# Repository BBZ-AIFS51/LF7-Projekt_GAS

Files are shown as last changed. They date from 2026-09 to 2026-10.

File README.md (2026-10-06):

<p align="center">
  Projekt GAS: mini security system with keypad, RFID reader and motion sensor
</p>

<p align="center">
  <a href="https://bbz-aifs51.github.io/LF7-Projekt_GAS/"><b>▶ Open the 3D model in your browser</b></a>
  &nbsp;·&nbsp; <a href="https://github.com/BBZ-AIFS51/LF7-Projekt_GAS/wiki">Project wiki (German)</a>
  &nbsp;·&nbsp; <a href="MDs/anleitung.md">User manual (German)</a>
  &nbsp;·&nbsp; <a href="Schaltplan/SCHALTPLAN.png">Schematic</a>
  &nbsp;·&nbsp; <a href="Code/alarm_system/alarm_system.ino">Firmware</a>
</p>

A small alarm system on an Arduino Uno R3, built as a school project for
learning field 7 (LF07). You arm and disarm it with a PIN on a 4x4 keypad or
with an RFID card. While it is armed, the motion sensor triggers a 30-second
siren. The OLED only shows icons: a heart when the system is disarmed, a skull
when it is armed, and a flashing skull during an alarm. You add cards right on
the device, no PC needed.

<p align="center">
  State machine: disarmed, exit delay, armed, alarm and admin menu
</p>

## Features

- **Two ways to arm and disarm:** PIN + `#` on the keypad, or a stored RFID card. Both do exactly the same thing.
- **Exit delay:** After arming you have 10 s to leave the room. The buzzer beeps once per second in the meantime.
- **Alarm:** It starts on motion (only while ARMED) or after **3 wrong tries** (wrong PIN or unknown card). The siren runs for 30 s or until the correct PIN or a known card is used.
- **Feedback:** A bright double tone means OK, a rough buzz means an error. The PIN only shows up as `*`, and a wrong entry briefly shows a ✖.
- **Admin menu on the device:** `A` + admin PIN + `#` opens it. There you add cards (just hold them to the reader), or browse and delete the stored ones. Cards live in the internal EEPROM and survive a new upload.
- **RFID reset:** `B` restarts the RC522 in case a clone module hangs.

## Quick controls

| Key | Action |
|---|---|
| `0`–`9` | enter the PIN (shown as `*`) |
| `#` | confirm the entry |
| `*` | clear the entry · in the admin menu: back / exit |
| `A` | while DISARMED: enter the admin PIN → admin menu |
| `B` | while DISARMED: re-initialise the RFID reader |
| Hold a card to the reader | same as the correct PIN (if the card is stored) |

The full end-user manual (in German) is in [MDs/anleitung.md](MDs/anleitung.md),
and as a PDF in [Anleitung/](Anleitung/Mini%20Security%20System%20Manual.pdf).

## Hardware

| Part | Uno connection | Note |
|---|---|---|
| Arduino Uno R3 | – | ATmega328P, 2 KB SRAM |
| 4x4 keypad | rows R1–R4 → D9–D6, columns C1–C4 → D5–D2 | the sketch scans the matrix itself |
| 1.3" OLED 128x64 | SDA → A4, SCL → A5 | **SH1106** controller, I²C address `0x3C` |
| RFID-RC522 | SS → A0, RST → A1, MOSI → D11, MISO → D12, SCK → D13 | **VCC to 3.3 V**, 5 V destroys the module |
| Motion sensor (PIR) | OUT → A2 | active HIGH |
| Passive buzzer | signal → D10 | driven directly from the pin, no transistor |
| 9 V battery | barrel jack | power supply |

All other VCC pins go to 5 V, all GND pins to a common ground. This uses up
almost every pin on the Uno; only A3 and D0/D1 (serial) are left free. The full parts list
is in [Teile.xlsx](Teile.xlsx).

<p align="center">
  Wiring of all parts to the Arduino Uno
</p>

The original Cirkit Designer schematic is in
[Schaltplan/](Schaltplan/SCHALTPLAN.png) (PNG and SVG).

## 3D-printed case

<p align="center">
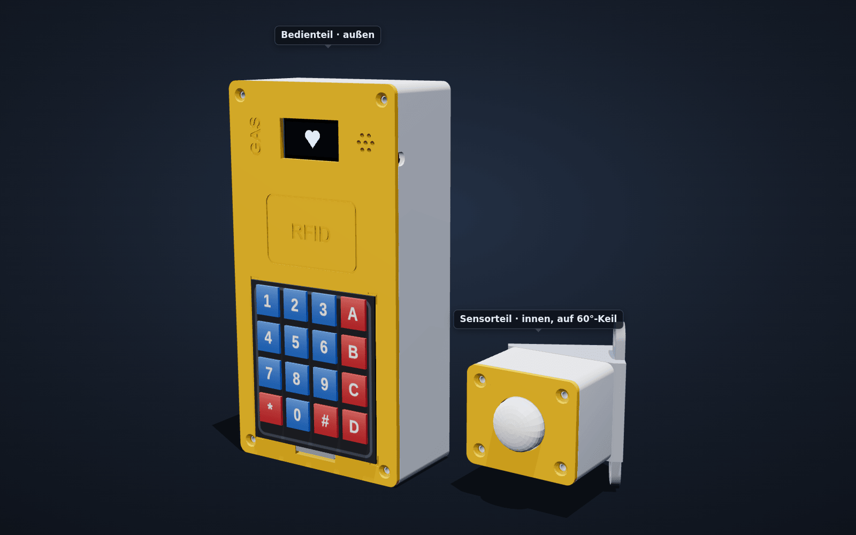
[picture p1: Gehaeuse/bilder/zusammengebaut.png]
Control unit with keypad, OLED and RFID field next to the sensor unit on its wedge
  
</p>

Two printed enclosures, connected by a 3-wire cable: the **control unit** (keypad,
OLED, RC522, buzzer, Uno) goes outside next to the door, the **sensor unit** sits
on the room side on a 60° wedge that turns it towards the entrance. The PIR can't
see through the wall, so standing at the keypad never triggers it. Five STL files,
no supports needed. Planning, print settings and assembly (in German):
[MDs/gehaeuse.md](MDs/gehaeuse.md), model and STLs: [Gehaeuse/](Gehaeuse/).

## Getting started

1. Install the **Arduino IDE** and get these libraries from the Library Manager:
   - **Adafruit SH110X** (also install its dependencies *Adafruit GFX* and *Adafruit BusIO*)
   - **MFRC522** (GithubCommunity)
   - **Keypad** (Mark Stanley / Alexander Brevig), only needed for `hardware_test`
   - `Wire`, `SPI` and `EEPROM` already come with the IDE.
2. Set the PIN and admin PIN at the top of [alarm_system.ino](Code/alarm_system/alarm_system.ino) (`PIN_CODE`, `ADMIN_PIN`).
3. Select the **Arduino Uno** board and the right port, then upload.
4. Set the serial monitor to **9600 baud**. On start-up it shows the RC522 version (`0x91`/`0x92` = OK), the number of stored cards and the free SRAM.
5. On the very first start the EEPROM is empty, so the sketch writes the factory list `DEFAULT_UIDS` into it. After that you manage cards only through the admin menu.

If something doesn't work, the test sketches check each part on its own:

| Sketch | Purpose |
|---|---|
| [Code/alarm_system/](Code/alarm_system/alarm_system.ino) | **Main firmware**: state machine, PIN, RFID, admin menu, sounds |
| [Code/hardware_test/](Code/hardware_test/hardware_test.ino) | bring-up test: OLED, keypad, buzzer, motion sensor |
| [Code/display_test/](Code/display_test/display_test.ino) | OLED only (icons + free SRAM) |
| [Code/rfid_test/](Code/rfid_test/rfid_test.ino) | RC522 only (version, UID of every card) |

## 3D model in the browser

**[▶ bbz-aifs51.github.io/LF7-Projekt_GAS](https://bbz-aifs51.github.io/LF7-Projekt_GAS/)**

An interactive 3D model of the build (three.js), laid out after the schematic.
It runs the firmware logic from `alarm_system.ino`, so the states, timings,
sounds and OLED graphics are the same:

- Press keys on the 3D keypad or in the side panel. Your keyboard works too (Enter = `#`, Esc = `*`).
- Click the cards or the key fob: they float over to the RC522 and the SPI lines light up.
- Click the motion sensor to trigger the alarm while ARMED.
- A signal pulse travels along each wire. A key press lights up exactly its row and column wire, and the L LED on D13 flickers during SPI traffic.
- The buzzer plays through WebAudio, and there is a serial monitor and an EEPROM card list.
- The **Enclosure** tab ([direct link](https://bbz-aifs51.github.io/LF7-Projekt_GAS/#enclosure)) puts the same parts into the 3D-printed case, built from the real STL files. Show the case solid, as X-ray or hidden, open it, and watch the signals run through the wires and the cable to the sensor unit.

The model uses demo PINs (`1234` and admin `0000`), not the real ones from the
sketch. To use it offline, just open
[docs/viewer/index.html](docs/viewer/index.html) in your browser.

## Pitfalls we solved

- **The OLED is an SH1106, not an SSD1306.** With the SSD1306 library it stays blank or only shows stripes. The right class is `Adafruit_SH1106G`.
- **SRAM is tight.** The OLED buffer alone takes 1024 of the 2048 bytes. With the Keypad library only ~205 bytes were left, which caused resets and wrong key presses. So the sketch scans the matrix itself, and all strings are kept in flash with `F()`.
- **`SPI.begin()` drives D10 HIGH**, because D10 is the AVR's SS pin. That is exactly where the buzzer sits, so the sketch sets the buzzer pin LOW only *after* `SPI.begin()`.
- **The motion sensor moved to A2**, because D11 is the fixed SPI MOSI pin. A2 works just like any digital pin with `digitalRead()`.
- **Polling the RC522 blocks for ~25 ms** when no card is present. So the sketch only polls the reader every 200 ms, otherwise the keypad gets sluggish and the siren stutters.

## Project structure

| Folder/file | Contents |
|---|---|
| [Code/](Code/) | Arduino sketches, one subfolder per sketch |
| [docs/](docs/) | animated README graphics (SVG), the 3D viewer (`docs/viewer/`) and the social preview image |
| [Gehaeuse/](Gehaeuse/) | 3D-printable case: OpenSCAD model, STL files, pictures |
| [tools/](tools/) | scripts that put the STLs into the viewer and render the pictures |
| [wiki/](wiki/) | source of the project wiki (German), published automatically by `.github/workflows/wiki.yml` |
| [MDs/](MDs/) | docs (German): [hardware spec](MDs/aufbau.md), [user manual](MDs/anleitung.md), [development log](MDs/entwicklungsverlauf.md) |
| [Anleitung/](Anleitung/) | user manual as a PDF |
| [Schaltplan/](Schaltplan/) | schematic (PNG/SVG) |
| [Teile.xlsx](Teile.xlsx) | parts list |
| [CLAUDE.md](CLAUDE.md) | project context and hardware facts for development with Claude Code |

The firmware was written together with Claude Code. Every prompt and answer is
logged (in German) in [MDs/entwicklungsverlauf.md](MDs/entwicklungsverlauf.md).
The school project documentation (assignment, team, schedule, costs, a visual
timeline of the development log, reflection) lives in the
[project wiki](https://github.com/BBZ-AIFS51/LF7-Projekt_GAS/wiki) (German). Its pages
are edited in [wiki/](wiki/); every push to `main` publishes them to the wiki.

## License

[MIT](LICENSE). The 3D viewer uses [three.js](https://threejs.org/) (MIT,
bundled as `docs/viewer/three.min.js`).

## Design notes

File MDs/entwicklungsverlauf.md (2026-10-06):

# Entwicklungsverlauf — Projekt GAS

Dokumentation der Firmware-Entwicklung mit Claude Code (Claude Opus 5).
Chronologisches Protokoll: Prompts (Jan Mummert) und Antworten (Claude).

- Projekt: LF07 — Mini-Sicherheitssystem / Access Lock (Arduino Uno R3)
- Daten der Sitzungen: 08.09.2026, 22.09.2026, 23.09.2026 (inkl. Gehäuse),
  29.09.2026, 30.09.2026, 06.10.2026
- Grundlagen im Kontext: [../CLAUDE.md](../CLAUDE.md), [aufbau.md](aufbau.md)

---

## 1. Prompt — Auftrag: komplette Firmware

> Use @CLAUDE.md und @MDs/aufbau.md.
>
> Programmiere den kompletten Code für unser Projekt.
>
> Was wir wollen: Ein mini Sicherheitssystem/Doorlock/Access Lock.
> Der Buzzer soll einen Alarmton abspielen, wenn der Motion sensor ausgelöst
> ist. Man soll die Alarmanlage mit einem Pin (später auch mit rfid, aber das
> ist nur eine Idee für ein feature wenn alles läuft) entschärfen können und
> auch wieder mit dem Pin scharf schalten können. Das Display soll im scharfen
> zustand einen Totenkopf anzeigen, wenn man Pin eingibt sollen anstelle des
> Pins nur Sternchen "*" angezeigt werden, die Eingabe des Pins soll man mit
> "#" bestätigen können. Bei richtigem Pin soll ein heller angenehmer
> Bestätigungston kommen, Bei Falsch eingabe ein Rauer längerer Ton (3sek).
> Bei 3 facher fehleingabe soll der Alarm der Anlage ertönen.
> Im Entsperrten zustand soll das Display ein Herz anzeigen.
>
> Im Unscharfen zustand soll der Motion Sensor natürlich keinen Alarm auslösen,
> nur wenn die Anlage scharf ist.
> Der Alarm soll extrem laut und schrill sein, er soll 30 sekunden dauern.

### Antwort

Fertig: [../Code/alarm_system/alarm_system.ino](../Code/alarm_system/alarm_system.ino)
— die komplette Firmware, Pins genau wie in aufbau.md/CLAUDE.md
(SDA=A4, SCL=A5, SH1106 @0x3C).

**Zustände**

- `UNSCHARF` — Herz auf dem Display, Bewegungssensor wird ignoriert.
- `SCHARF IN xs` — Ausgangsverzögerung (10 s, Piep pro Sekunde), damit du nach
  dem Scharfschalten den Raum verlassen kannst, ohne dich selbst auszulösen.
  Das hattest du nicht verlangt, ohne das löst die Anlage aber sofort beim
  eigenen Zurücktreten aus — Wert steht als `EXIT_DELAY_MS` oben, auf 0 setzen
  wenn du es nicht willst.
- `SCHARF` — Totenkopf, Bewegung (steigende Flanke auf D11) löst Alarm aus.
- `ALARM` — blinkendes „ALARM!!", Totenkopf, Restsekunden; Sirene 30 s, danach
  automatisch wieder scharf.

**Bedienung am Keypad**

- `0-9` PIN eingeben, auf dem Display nur `*` (Größe 2, mittig)
- `#` bestätigen → richtiger PIN schaltet scharf/unscharf und beendet den
  laufenden Alarm sofort
- `*` Eingabe löschen; halb getippte PIN verfällt nach 10 s von selbst
- PIN steht oben als `const char PIN_CODE[] = "1234";`

**Töne** (nicht-blockierend, Keypad bleibt währenddessen bedienbar)

- Richtig: zwei helle kurze Noten (G6 → C7)
- Falsch: rauer tiefer Brummton, 3 s (schnelles Wechseln 95/135 Hz)
- 3× falsch: voller Alarm — das gilt in jedem Zustand, also auch im unscharfen
  (Sabotage). Wenn du das nur im scharfen Zustand willst, sag Bescheid.
- Alarm: Sirenen-Sweep 2500↔3700 Hz, bewusst im lautesten Bereich des Piezos,
  30 s

**Nicht verifiziert:** Ich konnte den Sketch hier nicht kompilieren —
arduino-cli ist auf dem Rechner nicht vorhanden. Bitte einmal in der Arduino
IDE bauen und hochladen; die Bibliotheken sind dieselben wie beim
`hardware_test`.

---

## 2. Prompt — Display zeigt Pixelmüll

> Das Display bugt ein wenig, es zeigt weder das herz, noch einen totenkopf
> oder ähnliches an. Auch der Code etc. wird nicht richtig angezeigt. man kann
> die sekundne timer erahnen, aber das wars. Das display hat diese specs:
>
> - Module dimensions: 36 mm x 34 mm x 3 mm
> - Dot Matrix: 128 x 64
> - Pixel size: 0.21 mm × 0.21 mm
> - Pixel pitch: 0.23 mm × 0.23 mm
> - Display Mode: Passive Matrix
> - Duty: 1/64 Duty
> - Display Color: Blue
> - Interface: I2C
> - Power consumption: Less then 11mA
> - Size: 1.3 inch

### Antwort

Das klingt nach einem Anzeige-/Speicherproblem, nicht nach falscher Geometrie —
1,3" 128x64 I2C ist praktisch immer der SH1106, und der `hardware_test` lief ja.
Ich mache zwei Dinge: einen isolierten Display-Test zum Eingrenzen und die
Hauptfirmware deutlich RAM-sparsamer.

Der wahrscheinlichste Verdacht: Der Uno hat 2 KB SRAM, der Framebuffer belegt
davon allein 1 KB. `snprintf("%lu")` und die Text-Literale im RAM treiben den
Stack so weit hoch, dass er in den Framebuffer läuft — das ergibt genau so ein
Bild, in dem man Reste (die Sekundenzahlen) noch erahnen kann.

Zwei Sachen, bitte in dieser Reihenfolge testen:

**1. [../Code/display_test/display_test.ino](../Code/display_test/display_test.ino)
hochladen** (nur das Display, sonst nichts). Er zeigt im 2-Sekunden-Takt:
Rahmen+Text → Herz → Totenkopf → `****`, und schreibt vor jedem Bild den freien
SRAM in den Seriellen Monitor.

- Sehen die vier Bilder korrekt aus → das Display kann alles, das Problem ist
  der Speicher im Hauptsketch (siehe Punkt 2).
- Sind sie auch hier kaputt → es liegt am Display selbst; dann sag mir bitte,
  *wie* kaputt (verschoben, gestreift, Rauschen) und was der Rahmen macht. Dann
  ist der Controller vermutlich doch kein SH1106, und ich baue auf SSD1306 bzw.
  auf einen Spaltenversatz um.

**2. [../Code/alarm_system/alarm_system.ino](../Code/alarm_system/alarm_system.ino)
ist überarbeitet.** Was ich geändert habe und warum:

Der Uno hat 2048 Byte SRAM, davon frisst der OLED-Framebuffer allein 1024. Dazu
Keypad-Library, Wire- und Serial-Puffer — es bleiben nur ein paar hundert Byte
Stack. `snprintf("%lu")` braucht davon über 100 Byte auf einen Schlag, und die
Text-Literale `"UNSCHARF"` usw. lagen zusätzlich im RAM. Wenn der Stack in den
Framebuffer läuft, sieht man genau das, was du beschreibst: Pixelmüll, in dem
man Reste (deine Sekundenzahlen) noch erahnen kann.

Deshalb jetzt:

- kein `snprintf` mehr — der Countdown wird direkt mit `display.print()`
  ausgegeben
- alle Display-Texte über `F(...)` im Flash statt im RAM
- keine temporären `char`-Puffer mehr (die Sternchen werden in einer Schleife
  gedruckt)
- `setup()` gibt `free SRAM:` über Serial aus — der Wert sollte deutlich über
  250 liegen

Der Funktionsumfang ist unverändert. Die Icons habe ich zusätzlich leicht
anders positioniert, damit sich Totenkopf und die Sternchen-Zeile nicht mehr
überlappen.

Melde mir die vier Testbilder und den SRAM-Wert, dann weiß ich, in welche
Richtung es geht. Kompilieren kann ich hier weiterhin nicht — auf dem Rechner
ist keine arduino-cli installiert.

---

## 3. Prompt — Dokumentation

> Packe alle Prompts von mir und deine antworten in einer .md datei. wir
> brauchen das als dokumentation

### Antwort

Dieses Dokument. Es wird bei weiteren Änderungen fortgeschrieben.

---

## 4. Prompt — Resets beim Scharfschalten, Text soll weg

> Funktioniert soweit.
>
> 1. Sehr oft, nachdem es einmal armed und disarmed wurde kann man es nicht
>    erneut armen. Es zeigt im serial pin wrong an obwohl dieser richtig
>    eingegeben wurde:
>
>    ```
>    free SRAM: 205
>    [PIN] wrong 1
>    [PIN] correct
>    [STATE] arming - exit de=== Alarm system ready (disarmed) ===
>    PIN + '#' arms / disarms, '*' clears the entry.
>    free SRAM: 205
>    [PIN] wrong 1
>    ```
>
> 2. Entferne den Text bei den Symbolen, es soll nur Totenkopf oder Herz ohne
>    Text angezeigt werden. Der Sekundentimer ist etwas zu groß, die hälfte der
>    Zahl verschwindet weil es über den display rand hinaus geht.

### Antwort

**Zu 1 — der Arduino startet neu.** Im Log bricht die Zeile
`[STATE] arming - exit de` mitten im Wort ab und danach kommt wieder der
Startbanner `=== Alarm system ready ===`. Das ist ein Reset, kein Logikfehler.
Ursache ist der freie SRAM: **205 Byte**. Davon muss der komplette Stack leben,
inklusive der Interrupts, die `tone()` erzeugt (bei 3700 Hz sind das 7400
Interrupts pro Sekunde). Wenn so ein Interrupt zuschlägt, während der
Display-Code tief im Stack steht, läuft der Stack in den Framebuffer und in die
globalen Variablen — mal gibt es einen Reset, mal wird nur `entry[]` verfälscht,
und dann meldet der Sketch „PIN wrong" obwohl richtig getippt wurde. Das erklärt
auch, warum es erst *nach* dem ersten Scharfschalten auftritt: vorher hat noch
kein Ton gespielt.

Der größte Speicherfresser nach dem Framebuffer war die **Keypad-Library**: sie
hält 10 `Key`-Objekte, eine Bitmap und die Keymap im RAM, zusammen rund 120 Byte.
Die habe ich rausgeworfen und den 4x4-Scan selbst geschrieben — für eine Matrix
sind das ungefähr 30 Zeilen:

- Zeilen auf `INPUT_PULLUP`, Spalten hochohmig (`INPUT`)
- pro Scan eine Spalte auf `OUTPUT`/LOW ziehen und die vier Zeilen lesen
- Keymap liegt jetzt im Flash (`PROGMEM` + `pgm_read_byte`)
- eigenes Entprellen (20 ms), eine Taste wird genau einmal beim Drücken gemeldet

Damit sollten rund **320–330 Byte** frei sein. Der Wert steht wie vorher beim
Start im Seriellen Monitor — bitte einmal nachsehen und mir sagen, was dasteht.
Zusätzlich gibt der Sketch jetzt jede erkannte Taste (`[KEY] 4`) und die
komplette Eingabe vor der Prüfung (`[PIN] entered: 1234`) aus. Falls doch noch
etwas verschluckt wird, sieht man es damit sofort.

Die Keypad-Library wird für diesen Sketch nicht mehr gebraucht; der
`hardware_test` benutzt sie weiterhin, also bitte installiert lassen.

**Zu 2 — Anzeige.** Aller Statustext ist raus, es gibt nur noch die Icons:

- UNSCHARF: Herz, mittig
- SCHARF: Totenkopf, mittig
- Ausgangsverzögerung: Totenkopf + Countdown darunter
- ALARM: Totenkopf, der im 250-ms-Takt das ganze Display invertiert, darunter
  die Restsekunden (auch das „ALARM!!" ist weg — sagt Bescheid, wenn ihr das
  Wort zurückhaben wollt)

Der abgeschnittene Countdown war ein vertikales Problem, kein horizontales: die
Zahl stand in Größe 2 auf y = 52, das sind 16 Pixel Höhe bis y = 68 — das
Display hört bei 63 auf, also fehlte die untere Hälfte. Jetzt sitzt sie auf
y = 46 bzw. y = 47 und passt.

Während der PIN-Eingabe zeigt das Display nur noch die Sternchen, groß und
mittig. Grund: Totenkopf und Sternchen brauchen zusammen mehr als 64 Pixel Höhe,
sie hätten sich sonst überlappt.

---

## 5. Prompt — Kollisionserkennung und Rechtevergabe bei RFID

> Erkläre uns was unsere Lehrerin mit Kollisionserkennung und Rechtevergabe im
> bezug auf RFID meint

### Antwort

Zwei verschiedene Ebenen, die beim RFID-Teil oft durcheinander geworfen werden:

**Kollisionserkennung — Protokoll-Ebene (ISO 14443A)**

Liegen mehrere Karten gleichzeitig im Feld des RC522, würden bei einer
einfachen Anfrage alle gleichzeitig antworten — das ist eine *Kollision*. Der
ISO-14443A-Standard löst das über ein Anti-Kollisions-Verfahren: Der Reader
fragt die UID Bit für Bit in Kaskaden ab, bis genau eine Karte eindeutig
identifiziert ist. Bei uns läuft das komplett innerhalb der MFRC522-Library ab,
über die Aufrufe

```cpp
mfrc522.PICC_IsNewCardPresent()
mfrc522.PICC_ReadCardSerial()
```

in [readRfidUid()](../Code/alarm_system/alarm_system.ino#L326). Der Aufruf
[mfrc522.PICC_HaltA()](../Code/alarm_system/alarm_system.ino#L339) danach
schickt die gelesene Karte in den HALT-Zustand, damit sie nicht bei jedem
Poll-Zyklus erneut "kollidiert" bzw. neu gelesen wird, solange sie liegen
bleibt.

**Rechtevergabe — Anwendungsebene (Access Control)**

Unsere jetzige Logik ist rein binär: Eine UID steht in
[ALLOWED_UIDS](../Code/alarm_system/alarm_system.ino#L77) oder nicht, geprüft
in [isAllowedUid()](../Code/alarm_system/alarm_system.ino#L350) — jede erlaubte
Karte darf alles, was das System kann (scharf/unscharf schalten). Mit
"Rechtevergabe" ist vermutlich eine feinere Unterscheidung gemeint, z. B.:

- unterschiedliche Rollen pro Karte (manche dürfen nur entschärfen, andere
  auch neue Karten anlernen)
- Karten zur Laufzeit hinzufügen/entziehen können, statt sie fest im Code
  (`PROGMEM`) zu hinterlegen
- Protokollierung, wer wann welche Karte benutzt hat, statt nur ja/nein

Für den Umfang dieses Schulprojekts bleibt es bei der einfachen
Allow-List-Prüfung — das oben ist als konzeptionelle Erklärung für die
Dokumentation/Präsentation gedacht, nicht als Implementierungsauftrag.

---

## 6. Prompt — Rechtevergabe umsetzen: UIDs außerhalb des Codes verwalten

> Thema Rechtevergabe. Man soll die uids außerhalb des Codes verändern, bzw.
> sperren oder hinzufügen können. Wie könnte man das lösen. Plane erst

### Antwort

Aufbauend auf Eintrag 5 (dort nur konzeptionell besprochen, bewusst nicht
umgesetzt) jetzt tatsächlich implementiert, nach Rückfrage zur Bedienung:

- Admin-Interface komplett über Keypad + OLED (keine Serial-Kommandos, kein
  PC nötig)
- Löschen entfernt eine UID sofort, keine separate Sperrliste

**Speicherung:** UIDs liegen jetzt im internen EEPROM des Uno statt fest im
Code (`DEFAULT_UIDS` bleibt nur als Werksvorgabe fürs allererste Booten).
Kein Zusatzmodul (z. B. SD-Karte) nötig und laut CLAUDE.md auch gar nicht
möglich — kein Pin mehr frei. EEPROM übersteht ein Neu-Hochladen des Sketches.

**Bedienung:** Taste `A` im UNSCHARF-Zustand + eine eigene `ADMIN_PIN` + `#`
öffnet einen neuen Zustand `STATE_ADMIN` mit kleinem Text-Menü auf dem OLED
(bisher zeigte das Display nur Icons — hier bewusste Ausnahme, siehe
[Code/alarm_system/alarm_system.ino](../Code/alarm_system/alarm_system.ino#L885)):

- `1` Karte anlernen — auflegen genügt, kein manuelles Abtippen der Hex-UID
  mehr (das war vorher nötig, siehe `rfid_test.ino`)
- `2` Liste durchblättern (`#`), Karte löschen (`D`)
- `*` Menü verlassen; nach `ADMIN_IDLE_TIMEOUT_MS` (20 s) auch automatisch

Eine falsche Admin-PIN läuft über denselben `accessDenied()`-Pfad wie eine
falsche normale PIN — zählt also zu den 3 Fehlversuchen und löst genauso
Alarm aus (Bruteforce-Schutz für beide PINs einheitlich).

`MAX_STORED_UIDS` bewusst klein (8) gewählt wegen des knappen SRAMs (siehe
Memory Note in CLAUDE.md) — mehr Platz wäre im EEPROM (1024 Byte) locker da,
das RAM ist der eigentliche Engpass.

Vor der Änderung wurde eine Kopie der alten Version unter
`Code/alarm_system/alarm_system.ino.bak` gesichert.

**Offener Punkt:** Wie in Eintrag 4 — kein `arduino-cli` auf diesem Rechner,
der Sketch wurde nicht kompiliert. Vor dem Hochladen in der Arduino IDE
verifizieren und danach die Punkte aus dem Plan durchgehen (u. a.: passt
`free SRAM` noch, wandert die bestehende `DEFAULT_UIDS`-Karte korrekt ins
EEPROM, funktioniert Anlernen/Löschen, löst 3x falsche Admin-PIN den Alarm
aus, übersteht eine neue Karte ein erneutes Hochladen).

---

## 7. Prompt — RFID-Reset (22.09.2026)

> Unsere Lehrerin hat bei einer anderen Gruppe angemerkt, dass sie keinen
> RFID-Reset haben, da sich das RFID-Modul wohl öfters mal aufhängen kann.
> Wie könnten wir sowas bei uns einbauen, bzw. ist das überhaupt nötig? Falls
> ja könnte man da ja auch z. B. den Buchstaben B beim Tastenfeld setzen.

### Antwort

Ja, sinnvoll: RC522-Klone können SPI-seitig hängen bleiben (`VersionReg`
antwortet dann wieder mit `0x00`/`0xFF` statt `0x91`/`0x92`), erkennbar an
Karten, die plötzlich nicht mehr gelesen werden — sonst hilft nur ein
kompletter Neustart des Uno. `RST_PIN` (A1) ist bei uns ohnehin schon
verdrahtet, ein Reset zur Laufzeit ist also reine Software.

Rückfrage, ob nur manuell per Taste, zusätzlich automatisch im Hintergrund,
oder gar nicht — Antwort: nur manuell. Umgesetzt in
[../Code/alarm_system/alarm_system.ino](../Code/alarm_system/alarm_system.ino):

- Neue Funktion `resetRfid()` (`PCD_Reset()` + `PCD_Init()`, danach
  `VersionReg` neu geprüft und `rfidOk` aktualisiert; OK-/Fehlerton als
  Feedback)
- Taste `B` im Zustand UNSCHARF ruft `resetRfid()` auf — bisher unbelegt,
  analog zur `A`-Abfrage fürs Admin-Menü (nur bei `entryLen == 0`)
- Kopf-Kommentar im Sketch und [../CLAUDE.md](../CLAUDE.md) (Abschnitt
  „Sketches") entsprechend ergänzt

**Offener Punkt:** wie in den vorherigen Einträgen nicht kompiliert (kein
`arduino-cli` auf dem Rechner) — vor dem nächsten Hochladen in der Arduino
IDE prüfen, außerdem am echten Aufbau testen, ob `B` den Reader nach einem
gezielten Verbindungsabbruch (z. B. RST kurz trennen) tatsächlich wiederbelebt.

---

## 8. Prompt — 3D-Animationen und neue README (23.09.2026)

> Schaue dir dieses Github Repo von einem freund an:
> https://github.com/BBZ-AIFS51/LF7-MiniCasino
>
> Ich möchte das in dem Github repo von diesem Projekt auch so coole 3d
> animationen wie bei denen sind. Verwende dafür unsere dokumentation. Dabei
> kannst du Auch gleich die README unseres Projekts einmal komplett überarbeiten

### Antwort

Das MiniCasino-Repo nutzt zwei Dinge: animierte SVG-Grafiken direkt in der
README (CSS-Animationen, laufen auch auf GitHub) und einen three.js-3D-Viewer,
der über GitHub Pages läuft. Beides gibt es jetzt auch bei uns, aufgebaut aus
CLAUDE.md, aufbau.md, anleitung.md, dem Schaltplan und der Firmware:

- [../docs/banner.svg](../docs/banner.svg): isometrisches Gerät, das in 10 s
  einmal UNSCHARF → PIN → SCHARF → ALARM durchläuft. Herz und Totenkopf mit
  denselben Koordinaten wie `drawHeart()`/`drawSkull()`, die Alarm-Anzeige
  invertiert wie im Sketch, dazu eine schwebende RFID-Karte.
- [../docs/how-it-works.svg](../docs/how-it-works.svg): Zustandsautomat mit
  laufenden Pfeilen, dem jeweils aktiven Zustand und Fortschrittsbalken für
  10 s / 30 s.
- [../docs/wiring.svg](../docs/wiring.svg): Verdrahtung am Uno, Signalpulse
  zeigen die Richtung, Hinweis auf 3,3 V beim RC522.
- [../docs/viewer/index.html](../docs/viewer/index.html): 3D-Modell des
  Steckbrett-Aufbaus nach dem Schaltplan. Die Firmware-Logik ist 1:1 nach
  JavaScript übertragen (Zustände, Zeiten, Töne über WebAudio, OLED als
  128x64-Framebuffer mit denselben GFX-Aufrufen, Admin-Menü, EEPROM im
  localStorage). Tasten, Karten und PIR sind anklickbar, Signalpulse laufen
  über die Kabel. Im Modell gelten Demo-PINs (`1234`/`0000`), nicht die echten.
- [../.github/workflows/pages.yml](../.github/workflows/pages.yml): veröffentlicht
  den Viewer auf GitHub Pages.
- [../README.md](../README.md) komplett neu geschrieben.

Getestet: SVGs und Viewer im Edge (headless) gerendert, die Viewer-Logik mit
einem Skript durchgespielt (PIN, Ausgangszeit, Bewegung → Alarm,
3 Fehlversuche, Admin-PIN, Karte anlernen/löschen, 7-Byte-UID abgelehnt,
Eingabe-Timeout). Alle Prüfungen sind bestanden.

**Offener Punkt:** GitHub Pages muss einmalig unter *Settings → Pages →
Source: GitHub Actions* aktiviert werden. Der Fehlerton dauert laut Sketch
`ERROR_TONE_MS = 2000` (2 s), Kommentare und CLAUDE.md sagen noch 3 s.

---

## 9. Prompt — README, Grafiken und Viewer auf Englisch (23.09.2026)

> Ändere die Readme auf englisch
>
> Ja stelle auch den viewer auf englisch um und pushe alles dann

### Antwort

[../README.md](../README.md) ins Englische übersetzt (Inhalt unverändert,
deutsche Doku-Links mit „(German)“ markiert). Alle Texte in den drei SVGs unter
[../docs/](../docs/) und die komplette Oberfläche des 3D-Viewers (Seitenleiste,
Tooltips, Beschriftungen, Kartenaufdrucke) sind jetzt englisch. Die OLED- und
Serial-Texte waren schon englisch, weil sie aus dem Sketch stammen. Grafik und
Viewer danach erneut gerendert und geprüft.

---

## 10. Prompt — Gehäuse für den 3D-Druck (23.09.2026)

> Plane und entwerfe ein Gehäuse. Das Gehäuse soll 3D gedruckt werden. Ich habe
> 0 Erfahrung was sowas angeht.
>
> Wichtig ist, dass der Bewegungssensor auf der anderen seite sein muss, also
> quasi ist alles vorne an einer tür/Türrahmen und auch der anderen seite ist
> der bewegungssensor, sodass er halt erst was erkennt wenn man den raum
> betritt und nicht auslöst wenn man nur an den türrahmen rantritt um es zu
> entsperren.
>
> Plane erst das Gehäuse, dann entwerfe es

### Antwort

Zwei Gehäuse statt einem: **Bedienteil** außen neben der Tür (Uno, Keypad,
OLED, RC522, Buzzer, 90 × 176 × 45 mm) und **Sensorteil** innen im Raum
(HC-SR501, 52 × 44 × 35 mm), verbunden über ein 3-adriges Kabel. Der PIR sieht
nur in direkter Sichtlinie, die Wand verdeckt also die Person am Bedienteil.

- [gehaeuse.md](gehaeuse.md): Planung (Konzept, Aufteilung, Montageort) und
  Einsteiger-Anleitung (Nachmessen, Slicen, Einkaufsliste, Zusammenbau,
  Anpassen in OpenSCAD).
- [../Gehaeuse/gehaeuse.scad](../Gehaeuse/gehaeuse.scad): parametrisches
  OpenSCAD-Modell, alle Maße oben als Variablen.
- [../Gehaeuse/stl/](../Gehaeuse/stl/): vier fertige Druckteile, bereits in
  Druckrichtung, ohne Stützstrukturen druckbar.

Mit OpenSCAD 2021.01 gerendert: alle vier STLs sind geschlossen („Simple:
yes“). Die Frontansicht wurde auf nicht gespiegelte Gravuren geprüft.
**Offener Punkt:** Die Modulmaße stammen aus Datenblättern und sind nicht am
echten Aufbau gemessen. Außerdem ist noch nichts gedruckt.

---

## 11. Prompt — Sensor schräg zur Tür (29.09.2026)

> Passe montage.svg so an, dass der Sensor den Eingang abschirmt (grob im
> Bild angezeichnet). Passe außerdem sensor.png und die 3D-Dateien so an,
> dass der Sensor ein wenig angewinkelt an der Wand sitzt, sodass er den
> kompletten Eingang abschirmt.

### Antwort

Neues Druckteil **Keil** (`sensor_wedge`, 30°, 5–31 mm dick): wird mit zwei
Laschen an die Wand geschraubt, das unveränderte Sensor-Rückteil sitzt mit
2 Schrauben 3 × 10 mm darauf. Das dünne Ende zeigt zur Tür; bei 110°
Öffnungswinkel liegt die türseitige Kante des Erfassungsbereichs dann fast
parallel zur Wand, der ganze Eingang ist im Sichtfeld. Für die andere Türseite
wird der Keil um 180° gedreht.

- `montage.svg`: Erfassungsbereich um 30° zur Tür gedreht, Keil eingezeichnet.
  Außerdem das Türscharnier auf die andere Seite gelegt — sonst stünde die
  geöffnete Tür genau zwischen Sensor und Eingang.
- `sensor.png`, `explosion.png`, `zusammengebaut.png` neu gerendert,
  `stl/sensor_wedge.stl` neu (geschlossen, „Simple: yes“). Die übrigen STLs
  sind unverändert.
- [gehaeuse.md](gehaeuse.md): Keil, Montage, Einkaufsliste ergänzt.

---

## 12. Prompt — Sensor noch stärker zur Tür (29.09.2026)

> Noch mehr die Tür abdecken, sodass sich der Sensorbereich stark mit der
> Wand überschneidet.

### Antwort

Keil von 30° auf **60°** (`su_angle`), jetzt 5–50 mm dick. Die türseitige
Kante des Erfassungsbereichs läuft damit ca. 25° in die Wand hinein, die
andere zeigt fast gerade in den Raum. Damit die Schraubenlöcher am dicken
Ende nicht hinten aus dem Keil kommen, hat er dort 4 mm zusätzliches Material
(`wedge_back`). `montage.svg` (Kegel an der Wandaußenseite abgeschnitten, weil
der PIR nicht durch die Wand sieht), `sensor.png`, `explosion.png`,
`zusammengebaut.png` und `stl/sensor_wedge.stl` („Simple: yes“) neu erzeugt.

---

## 13. Prompt — Vorschaubilder, Gehäuse im 3D-Viewer, Social Preview (30.09.2026)

> 1. Überarbeite Optisch nochmal die Vorschauen für das 3D-Druck Modell.
> 2. Ergänze beim 3D-Modell im Browser noch einen Tab, in welchem das ganze
>    nicht nur lose da liegt, sondern auch im Gehäuse ist. Das Gehäuse soll bei
>    diesem Modell dann quasi durchsichtig oder umschaltbar sein
> 3. Erstelle ein Passendes Social Media Preview nach den vorgaben von gitbhub

### Antwort

**Gehäuse im 3D-Viewer:** neuer Tab **Enclosure** (Direktlink
`…/LF7-Projekt_GAS/#enclosure`). Bedienteil vorne auf einem Demo-Brett (spielt
die Wand), Sensorteil auf dem 60°-Keil auf der Rückseite, 3-adriges Kabel durch
das Brett. Innen sitzen Uno, Keypad, OLED, RC522, Buzzer und ein Mini-Breadboard
an den Positionen aus `gehaeuse.scad`, alle Kabel sind verlegt. Das Gehäuse lässt
sich **Solid / X-ray / Hidden** schalten und mit **Open** aufklappen. Die
Firmware läuft weiter: Tasten, Karten (fliegen ans RFID-Feld), Bewegungsmelder
(Signal läuft sichtbar übers Kabel, der Erfassungsbereich leuchtet auf).
Die Gehäuseteile sind keine Nachbauten, sondern die echten STL-Dateien:
`tools/stl2viewer.mjs` packt sie kompakt in `docs/viewer/enclosure.js` (233 KB,
funktioniert auch offline). Nebenbei die Befestigungslöcher des Uno im Viewer
auf die echten R3-Maße korrigiert, damit er auf den Abstandshaltern sitzt.

**Vorschaubilder:** alle sechs Bilder in `Gehaeuse/bilder/` neu, jetzt im Stil
der README-Grafiken (dunkler Hintergrund, weiche Schatten, Studio-Licht,
Beschriftungen auf Deutsch) und mit den detaillierten Bauteilen aus dem Viewer
statt der groben OpenSCAD-Platzhalter. Neu dazu `druckplatte.png`: alle fünf
Teile so, wie sie auf dem Druckbett liegen (in `gehaeuse.md` bei „Slicen“).
Erzeugt werden die Bilder von `tools/render.mjs` über den Viewer (Playwright),
optional mit pngquant verkleinert (je 35–115 KB).

**Social Preview:** `docs/social-preview.png`, 1280 × 640 px (GitHub-Empfehlung,
Minimum 640 × 320), PNG unter 1 MB (135 KB), wichtige Inhalte mit Abstand zum
Rand. Titel, Kurzbeschreibung und die vier Funktionen wie im Banner, rechts das
Gehäuse im X-ray-Modus. Vorlage: `tools/social-preview.html`. **Muss von Hand
hochgeladen werden:** Repository → Settings → General → Social preview → Edit →
Upload an image (dafür gibt es keine API).

---

## 14. Prompt — Banner und Social Preview mit Gehäuse (30.09.2026)

> dann aktualisiere auch docs/banner.svg, sodass auch dort sowie auf dem social
> preview banner das ganze im gehäuse drauf ist

### Antwort

- `docs/banner.svg`: Statt der flachen Platine zeigt das Banner jetzt das
  Bedienteil im Gehäuse (isometrisch, stehend) und daneben das Sensorteil auf
  dem 60°-Keil. Alle Positionen stammen aus `gehaeuse.scad`: OLED-Fenster,
  Schalllöcher, „GAS“- und „RFID“-Gravur, Keypad, Kabelschlitz, Schrauben.
  Die Animation läuft wie vorher: Herz, PIN-Eingabe mit Tastendrücken,
  Totenkopf, Alarm mit Blinken, rotem Schein und Ringen an Buzzer und
  Bewegungsmelder. Die Karte schwebt vor dem RFID-Feld. Weiterhin reines SVG
  mit CSS-Animation (19 KB), keine eingebetteten Bilder.
- `docs/social-preview.png`: Gehäuse jetzt massiv statt X-ray, damit klar das
  fertige Gerät zu sehen ist (1280 × 640, 110 KB). Muss danach wieder unter
  Settings → General → Social preview hochgeladen werden.

---

## 15. Prompt — Holo-Look für Banner und Social Preview (30.09.2026)

> Mace es so im holo look, also durchsichtig wie auf dem social preview
> *(dazu ein Screenshot des Social Preview mit dem durchsichtigen X-ray-Gehäuse)*

### Antwort

- `docs/banner.svg` zeigt das Gehäuse jetzt im X-ray-Look: Bedienteil und
  Sensorteil durchsichtig, innen sind Uno, OLED, RC522, Breadboard und die
  Kabel zu sehen. Die Grafik ist ein Render aus dem 3D-Viewer, als Bild ins
  SVG eingebettet (120 KB). Die Animation liegt als SVG-Ebenen passgenau
  darüber: OLED (Herz → `****` → Totenkopf → Alarm), Tastendrücke, pulsierendes
  RFID-Feld, Karte, Ringe an Buzzer und Bewegungsmelder im Alarm.
- Das Banner wird jetzt erzeugt: `node tools/render.mjs banner` füllt die
  Vorlage `tools/banner.svg`. Die Lage der Ebenen rechnet das Skript aus dem
  3D-Modell aus (Punkte der Frontplatten werden auf das Bild projiziert).
- `docs/social-preview.png` wieder mit durchsichtigem Gehäuse (136 KB), wie
  vorher.

---

## 16. Prompt — Falsche Eingabe bricht den Alarm ab (06.10.2026)

> Wenn der Alarm ausgelöst wurde und man einen Falschen Code oder Falsche
> karte eingibt. Dann geht kurz der Buzzer mit dem "Falsch" Ton, der alarm
> geht aber nicht weiter danach.
>
> Der Alarm soll während die Anlage ausgelöst ist natürlich nicht unterbrochen
> oder abgebrochen werden können, außer durch die eingabe des richtigen
> Codes/Karte

### Antwort

**Ursache:** `accessDenied()` hat bei jeder Fehleingabe `startSound(SOUND_ERROR)`
gerufen. Das hat die Sirene durch den Fehlerton ersetzt. Nach dessen Ende war
Stille, obwohl der Zustand noch ALARM war.

**Fix:** In
[../Code/alarm_system/alarm_system.ino](../Code/alarm_system/alarm_system.ino)
kehrt `accessDenied()` im Zustand `STATE_ALARM` sofort zurück. Die Sirene läuft
weiter, es gibt keinen Fehlerton, keinen Neustart des Alarms und keinen
gezählten Fehlversuch. Nur die richtige PIN oder eine bekannte Karte beendet
den Alarm (über `accessGranted()`). Serial meldet
`[ALARM] wrong entry ignored, siren keeps running`. Gleiche Änderung im
3D-Viewer ([../docs/viewer/index.html](../docs/viewer/index.html)) und ein Satz
in [../CLAUDE.md](../CLAUDE.md).

Unverändert: Nach `ALARM_MS` (30 s) geht die Sirene weiterhin von selbst aus
und die Anlage ist wieder scharf (so in Eintrag 1 gewünscht).

**Offener Punkt:** nicht kompiliert und nicht am Aufbau getestet.

---

## 17. Prompt — Projekt-Wiki (06.10.2026)

Vorher in derselben Sitzung: Vorschläge, wie man das GitHub-Wiki sinnvoll
nutzen kann, ein Plan für die Projektdokumentation und welche
Gestaltungsmittel das Wiki erlaubt. Dann:

> Wiki page ist erstellt. Tob dich aus.
>
> Plane erst genau was du reinpacken willst, damit nichts vergessen wird.
> Packe platzhalter für dinge rein die wir später reinschreiben sollen. Halte
> dich an die vorgaben der claude.md im repository.
>
> Die Reflexion schreiben wir später, packe einen platzhalter rein
> Der Entwicklungsverlauf aus entwicklungsverlauf.md ist wichtig. Er soll schön
> visualisiert in der Wiki auftauchen.

### Antwort

Das Wiki (eigenes Git-Repo `LF7-Projekt_GAS.wiki.git`) enthält jetzt die
Projektdokumentation auf Deutsch: Home, Projektauftrag, Team und Rollen,
Zeitplan, Kosten, Umsetzung, Entwicklungsverlauf, KI-Einsatz, Fazit und
Reflexion, dazu Seitenleiste und Fußzeile.

- **Keine doppelte Technik-Doku:** Pins, Code und Bauanleitung bleiben im
  Repository, das Wiki verlinkt darauf. Bilder werden direkt aus dem Repo
  eingebunden, nicht kopiert.
- **Entwicklungsverlauf:** Zeitleiste nach Sitzungen, ein Diagramm, wie die
  Prompts aufeinander aufbauen, Verteilung nach Themen und pro Prompt eine
  Karte (Anlass, Prompt im Wortlaut zum Aufklappen, Ergebnis, offene Punkte,
  Link auf den vollen Eintrag hier).
- **Diagramme** als Mermaid direkt im Wiki: Gantt-Diagramm (Ist-Ablauf),
  Systemüberblick, Zustandsautomat, Arbeitsablauf mit der KI.
- **Platzhalter** (`✏️ TODO`) für alles, was nur das Team weiß: Team und
  Rollen, Projektauftrag im Wortlaut, Preise, Soll-Zeitplan, Fotos und die
  Reflexion.
- [../CLAUDE.md](../CLAUDE.md) beschreibt das Wiki jetzt und sagt, was bei
  Änderungen mitgezogen werden muss. Die README verlinkt es.

**Offener Punkt:** Die Prompts 1–6 sind hier nicht einzeln datiert. Im
Gantt-Diagramm stehen sie deshalb als ein Zeitraum vom 08.09. bis 22.09.

---

## 18. Prompt — Projektdoku nach den Vorgaben (06.10.2026)

Mit angehängt: die Vorgaben der Lehrkraft „Projektdokumentation und
Präsentation“ (zehn Kapitel von Deckblatt bis Quellenverzeichnis, Regeln zum
KI-Einsatz, Ablauf der Präsentation).

> Das hier sind unsere Projektvorgaben. Du kannst ja in der Wiki nochmal den
> Rest vervollständigen den du da noch raus nehmen kannst.
>
> Entwerfe einen Plan/Idee wie man die ganze abgabe des Projekts gestalten
> könnte

### Antwort

Das Wiki folgt jetzt den zehn Kapiteln der Vorgabe. Seitenleiste und
Startseite sind danach nummeriert, jede Kapitelseite hat Vor-/Zurück-Links.

| Kapitel | Wiki-Seite |
|---|---|
| 1 Deckblatt | `Home` (Titel, Gruppe, Klasse, Datum als ✏️ TODO) |
| 2 Idee und Zielsetzung | `Idee-und-Zielsetzung` (vorher `Projektauftrag`) |
| 3 Funktionsbeschreibung | `Funktionsbeschreibung` (neu: Alltag, Zustände, Rückmeldungen, Admin-Menü) |
| 4 Verwendete Bauteile | `Verwendete-Bauteile` (neu) |
| 5 Aufbau und Schaltplan | `Aufbau-und-Schaltplan` (neu: Schaltplan, Pin-Zuordnung, Platz fürs Foto) |
| 6 Sourcecode | `Sourcecode` (neu: Dateiliste, Konstanten) |
| 7 Wichtige Codeabschnitte | `Wichtige-Codeabschnitte` (neu: 8 Abschnitte mit kurzen Auszügen) |
| 8 Herausforderungen | `Herausforderungen` (neu: Situation, Ursache, Lösung pro Bauteil) |
| 9 Fazit und Ausblick | `Fazit-und-Ausblick` (vorher `Fazit-und-Reflexion`) |
| 10 Quellenverzeichnis | `Quellenverzeichnis` (neu) |

Team, Zeitplan, Kosten, Projektphasen (vorher `Umsetzung`), Entwicklungsverlauf
und KI-Einsatz stehen als Anhang.

- **Prompts nicht abdrucken:** Die Vorgabe verbietet Prompts in der
  Dokumentation. Die Prompts im Wortlaut sind aus dem Wiki entfernt, die
  Karten im Entwicklungsverlauf heißen „Schritt“ statt „Prompt“.
- **Technik im Wiki:** Die Vorgabe verlangt Pin-Zuordnung und Code-Erklärungen
  in der Dokumentation. Die Regel „keine Technik-Doku im Wiki“ in
  [../CLAUDE.md](../CLAUDE.md) ist entsprechend angepasst.
- **Korrektur:** Neben D0/D1 ist am Uno auch A3 noch frei (CLAUDE.md und
  README sagten „nur D0/D1“).
- Dazu ein Vorschlag für die gesamte Abgabe (Abgabepaket, Präsentation,
  Live-Demo), nur im Chat.

**Offene Punkte:** Klären, ob dieses Protokoll mit den Prompts im Wortlaut als
Anhang erlaubt ist. Fehlerton weiterhin 2 s statt der geforderten 3 s.

---

## 19. Prompt — Wiki automatisch veröffentlichen (06.10.2026)

Vorher: Claude Code kann aus der Cloud-Sitzung nicht direkt ins Wiki-Repo
pushen, die Seiten mussten als ZIP von Hand hochgeladen werden. Auf die Frage

> wie kann ich am besten die wiki aktualisieren, ohne alles manuell auf github
> zu pasten

kam der Vorschlag, die Seiten im Repo abzulegen und per GitHub Action zu
veröffentlichen. Dann:

> Ja dann mach das, also setze es um mit dem workflow usw

### Antwort

- **[../wiki/](../wiki/)** enthält jetzt alle 18 Wiki-Seiten (Stand aus
  Eintrag 18). Jede Seite beginnt mit einem HTML-Kommentar, dass sie aus
  diesem Ordner erzeugt wird, die Fußzeile hat einen Link „Wiki bearbeiten“.
- **[../.github/workflows/wiki.yml](../.github/workflows/wiki.yml)** läuft bei
  jedem Push nach `main`, der `wiki/` ändert (oder von Hand über „Run
  workflow“): Wiki-Repo klonen, `wiki/` hineinspiegeln (alles außer `.git` löschen, dann kopieren),
  committen, pushen. Kein fremdes Action-Paket, nur der eingebaute
  `github.token` mit `contents: write`. Ohne Änderungen wird nichts committet.
- Weil gespiegelt wird, verschwinden die umbenannten alten Seiten
  (Projektauftrag, Umsetzung, Fazit und Reflexion) beim ersten Lauf aus dem
  Wiki.
- Hinweise in den Seiten angepasst: eigene Bilder nach `wiki/images/`, Einbindung
  per `raw.githubusercontent.com`-URL.
- [../CLAUDE.md](../CLAUDE.md) und README beschreiben den neuen Ablauf.

**Wichtig fürs Team:** Das Wiki ab jetzt nur noch im Ordner `wiki/` bearbeiten
(auf GitHub: Datei öffnen → Stift-Symbol). Änderungen im Wiki-Web-Editor werden
beim nächsten Lauf überschrieben.

---

## Anhang — Stand der Dateien

| Datei | Zweck |
|---|---|
| [../Code/hardware_test/hardware_test.ino](../Code/hardware_test/hardware_test.ino) | Bring-up-Test aller Bauteile (vor dieser Sitzung entstanden) |
| [../Code/alarm_system/alarm_system.ino](../Code/alarm_system/alarm_system.ino) | Hauptfirmware: Zustandsautomat, PIN, Icons, Töne |
| [../Code/display_test/display_test.ino](../Code/display_test/display_test.ino) | Isolierter OLED-Test + SRAM-Anzeige zur Fehlersuche |
| [../CLAUDE.md](../CLAUDE.md) | Projektvorgaben, Pinbelegung, Hardware-Fakten, SRAM-Hinweis |

**Offener Punkt:** Die Reset-Diagnose (zu wenig freier SRAM) gilt erst als
bestätigt, wenn der neue `free SRAM:`-Wert im Seriellen Monitor deutlich über
300 liegt und die Resets ausbleiben. Kein Sketch
dieser Sitzung wurde kompiliert, da auf dem Rechner keine arduino-cli vorhanden
ist.

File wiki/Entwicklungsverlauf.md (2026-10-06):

<!-- Diese Seite wird automatisch aus dem Ordner wiki/ im Repository erzeugt. Änderungen im Wiki-Editor werden beim nächsten Abgleich überschrieben. Bearbeiten: https://github.com/BBZ-AIFS51/LF7-Projekt_GAS/tree/main/wiki -->
# 🧭 Entwicklungsverlauf

<sub>Anhang</sub>

Die Firmware, das 3D-Modell und das Gehäuse sind Schritt für Schritt entstanden,
mit dem KI-Assistenten **Claude Code** als Hilfsmittel (siehe
[KI-Einsatz](KI-Einsatz)). Diese Seite zeigt den Verlauf als Zeitleiste: pro
Arbeitsschritt, was wir erreichen wollten oder welches Problem auftrat, und was
dabei herauskam.

> [!TIP]
> Das ausführliche Arbeitsprotokoll liegt im Repository unter
> [MDs/entwicklungsverlauf.md](https://github.com/BBZ-AIFS51/LF7-Projekt_GAS/blob/main/MDs/entwicklungsverlauf.md).
> Unter jeder Karte führt ein Link direkt zum passenden Eintrag.

| **19** | **6** | **3** | **2** |
|:---:|:---:|:---:|:---:|
| Arbeitsschritte | Sitzungen | Fehler gefunden und behoben | Anregungen der Lehrkraft umgesetzt |

## Überblick

### Zeitleiste

```mermaid
timeline
    title Projekt GAS – Arbeitsschritte nach Sitzung
    section Firmware
        ab 08.09. : S1 Komplette Firmware
                  : S2 Display zeigt Pixelmüll
                  : S3 Dokumentation
                  : S4 Neustarts und Speicher
                  : S5 RFID-Begriffe erklärt
                  : S6 Admin-Menü für Karten
        22.09. : S7 RFID-Reset
    section Darstellung und Gehäuse
        23.09. : S8 README und 3D-Modell
               : S9 Alles auf Englisch
               : S10 Gehäuse-Entwurf
        29.09. : S11 Sensor-Keil 30 Grad
               : S12 Sensor-Keil 60 Grad
        30.09. : S13 Gehäuse im 3D-Modell
               : S14 Banner mit Gehäuse
               : S15 Holo-Look
    section Feinschliff
        06.10. : S16 Bugfix Alarm
               : S17 Projekt-Wiki
               : S18 Doku nach Vorgaben
               : S19 Wiki automatisch
```

### Wie die Schritte aufeinander aufbauen

Kaum ein Schritt steht für sich. Meist hat ein Ergebnis die nächste Frage
ausgelöst: ein Fehler beim Testen, eine Anregung der Lehrkraft oder eine neue
Idee.

```mermaid
flowchart LR
    P1["💻 S1<br/>Firmware"]
    P2["🐞 S2<br/>Pixelmüll"]
    P3["📝 S3<br/>Protokoll"]
    P4["🐞 S4<br/>Neustarts"]
    P5["💡 S5<br/>RFID-Begriffe"]
    P6["💻 S6<br/>Admin-Menü"]
    P7["💻 S7<br/>RFID-Reset"]
    P8["🎨 S8<br/>README + 3D"]
    P9["🎨 S9<br/>Englisch"]
    P10["📦 S10<br/>Gehäuse"]
    P11["📦 S11<br/>Keil 30°"]
    P12["📦 S12<br/>Keil 60°"]
    P13["🎨 S13<br/>Gehäuse im 3D"]
    P14["🎨 S14<br/>Banner"]
    P15["🎨 S15<br/>Holo-Look"]
    P16["🐞 S16<br/>Bugfix Alarm"]
    P17["📝 S17<br/>Wiki"]
    P18["📝 S18<br/>Vorgaben"]
    P19["📝 S19<br/>Wiki-Workflow"]

    P1 -- "Test am Gerät" --> P2 -- "zu wenig SRAM" --> P4
    P1 -. "Lehrkraft" .-> P5 --> P6
    P6 -. "Lehrkraft" .-> P7
    P1 -- "Test am Gerät" --> P16
    P8 --> P9
    P8 --> P13
    P10 --> P11 --> P12 --> P13
    P13 --> P14 --> P15
    P3 --> P17
    P17 -. "Lehrkraft" .-> P18
    P18 --> P19

    classDef fw fill:#d0e7ff,stroke:#0969da,color:#0a3069
    classDef bug fill:#ffd8d3,stroke:#cf222e,color:#82071e
    classDef info fill:#fff1c2,stroke:#9a6700,color:#4d2d00
    classDef vis fill:#ead9ff,stroke:#8250df,color:#3e1f79
    classDef box fill:#d2f4dc,stroke:#1a7f37,color:#044f1e
    classDef doc fill:#e6e9ed,stroke:#59636e,color:#1f2328
    class P1,P6,P7 fw
    class P2,P4,P16 bug
    class P5 info
    class P8,P9,P13,P14,P15 vis
    class P10,P11,P12 box
    class P3,P17,P18,P19 doc
```

<sub>Durchgezogene Pfeile: Ergebnis führt direkt zum nächsten Schritt · gestrichelt: Anregung der Lehrkraft</sub>

### Themenbereiche

<table>
<tr>
<td width="55%">

| | Bereich | Schritte |
|:---:|---|---|
| 💻 | Firmware-Funktionen | 1, 6, 7 |
| 🐞 | Fehlerbehebung | 2, 4, 16 |
| 💡 | Erklärung / Wissen | 5 |
| 🎨 | Darstellung (README, 3D-Modell, Grafiken) | 8, 9, 13, 14, 15 |
| 📦 | Gehäuse | 10, 11, 12 |
| 📝 | Dokumentation | 3, 17, 18, 19 |

</td>
<td width="45%">

```mermaid
pie
    "Firmware" : 3
    "Fehlerbehebung" : 3
    "Erklärung" : 1
    "Darstellung" : 5
    "Gehäuse" : 3
    "Dokumentation" : 4
```

</td>
</tr>
</table>

---

## 📆 Ab 08.09.2026 · Die Firmware entsteht

<sub>Die Schritte 1–6 sind im Protokoll nicht einzeln datiert. Sie liegen zwischen der ersten Sitzung am 08.09. und dem 22.09.</sub>

### 💻 Schritt 1 — Auftrag: komplette Firmware

**Wir wollten:** die komplette Firmware für unser Mini-Sicherheitssystem, mit PIN, Totenkopf und Herz, Tönen und 30-Sekunden-Alarm.

**Ergebnis**
- Zustandsautomat: Unscharf → Ausgangsverzögerung → Scharf → Alarm
- PIN-Eingabe mit `*`-Maske, Bestätigung mit <kbd>#</kbd>, Löschen mit <kbd>*</kbd>
- Nicht blockierende Töne: heller Doppelton, rauer Fehlerton, Sirenen-Sweep 30 s
- **Von der KI ergänzt:** 10 s Ausgangsverzögerung, damit man sich beim Verlassen des Raums nicht selbst auslöst

> [!WARNING]
> **Offen:** Der Sketch konnte von der KI nicht kompiliert werden. Bauen und Testen in der Arduino IDE lag bei uns.

<sub>📄 [`alarm_system.ino`](https://github.com/BBZ-AIFS51/LF7-Projekt_GAS/blob/main/Code/alarm_system/alarm_system.ino) · 🔗 [Vollständiger Eintrag](https://github.com/BBZ-AIFS51/LF7-Projekt_GAS/blob/main/MDs/entwicklungsverlauf.md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)</sub>

### 🐞 Schritt 2 — Display zeigt Pixelmüll

**Problem:** Das Display zeigt weder Herz noch Totenkopf, nur der Sekunden-Countdown ist zu erahnen.

**Ergebnis**
- **Ursache:** zu wenig Arbeitsspeicher. Der Uno hat 2048 Byte, das Display belegt allein 1024. Der Stack lief in den Display-Puffer.
- Neuer isolierter Test [`display_test.ino`](https://github.com/BBZ-AIFS51/LF7-Projekt_GAS/blob/main/Code/display_test/display_test.ino), der den freien SRAM ausgibt
- Firmware sparsamer: alle Texte mit `F()` im Flash, kein `snprintf`, keine Textpuffer

<sub>🔗 [Vollständiger Eintrag](https://github.com/BBZ-AIFS51/LF7-Projekt_GAS/blob/main/MDs/entwicklungsverlauf.md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üll)</sub>

### 📝 Schritt 3 — Dokumentation

**Wir wollten:** alle Arbeitsschritte und Ergebnisse als Protokoll festhalten.

**Ergebnis**
- Das Protokoll [`entwicklungsverlauf.md`](https://github.com/BBZ-AIFS51/LF7-Projekt_GAS/blob/main/MDs/entwicklungsverlauf.md). Es wird seitdem bei jeder Änderung fortgeschrieben und ist die Grundlage dieser Seite.

<sub>🔗 [Vollständiger Eintrag](https://github.com/BBZ-AIFS51/LF7-Projekt_GAS/blob/main/MDs/entwicklungsverlauf.md#3-prompt--dokumentation)</sub>

### 🐞 Schritt 4 — Neustarts beim Scharfschalten, Text soll weg

**Problem:** Nach einmal Scharf- und Unscharfschalten wird die richtige PIN als falsch erkannt. Außerdem soll das Display nur Symbole zeigen, und der Countdown ist abgeschnitten.

**Ergebnis**
- **Diagnose aus unserem Log:** Die Zeile bricht mitten im Wort ab, danach erscheint wieder der Startbildschirm. Der Arduino startet also neu, weil nur 205 Byte SRAM frei sind.
- Keypad-Library entfernt, die Tastenmatrix wird selbst gescannt (spart ~120 Byte)
- Display zeigt nur noch Symbole. Der Countdown ragte unten über den Rand und sitzt jetzt höher.

<sub>🔗 [Vollständiger Eintrag](https://github.com/BBZ-AIFS51/LF7-Projekt_GAS/blob/main/MDs/entwicklungsverlauf.md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)</sub>

### 💡 Schritt 5 — Kollisionserkennung und Rechtevergabe bei RFID

**Frage:** Was meint unsere Lehrerin mit „Kollisionserkennung“ und „Rechtevergabe“ bei RFID?

**Ergebnis**

| Begriff | Ebene | Bei uns |
|---|---|---|
| **Kollisionserkennung** | Protokoll (ISO 14443A): Liegen mehrere Karten im Feld, fragt der Leser die UID Bit für Bit ab, bis genau eine Karte übrig bleibt | erledigt die MFRC522-Library, `PICC_HaltA()` schickt die gelesene Karte schlafen |
| **Rechtevergabe** | Anwendung: Wer darf was? | damals nur eine feste Liste erlaubter Karten im Code |

Bewusst nur erklärt, nicht umgesetzt. Die Umsetzung folgte in Schritt 6.

<sub>🔗 [Vollständiger Eintrag](https://github.com/BBZ-AIFS51/LF7-Projekt_GAS/blob/main/MDs/entwicklungsverlauf.md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)</sub>

### 💻 Schritt 6 — Rechtevergabe umsetzen: Karten außerhalb des Codes verwalten

**Wir wollten:** Karten hinzufügen und sperren können, ohne den Code zu ändern. Erst planen, dann umsetzen.

**Ergebnis**
- 💬 **Rückfrage der KI** zur Bedienung. Unsere Entscheidung: nur über Keypad und Display (kein PC), Löschen statt Sperrliste
- Karten liegen im **EEPROM** und überstehen ein neues Hochladen, maximal 8 Karten
- **Admin-Menü:** <kbd>A</kbd> + Admin-PIN, dann <kbd>1</kbd> Karte anlernen (einfach auflegen) und <kbd>2</kbd> Liste durchblättern / mit <kbd>D</kbd> löschen
- Eine falsche Admin-PIN zählt als Fehlversuch (Schutz gegen Durchprobieren)

<sub>🔗 [Vollständiger Eintrag](https://github.com/BBZ-AIFS51/LF7-Projekt_GAS/blob/main/MDs/entwicklungsverlauf.md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ßerhalb-des-codes-verwalten)</sub>

---

## 📆 22.09.2026 · RFID-Reset

### 💻 Schritt 7 — RFID-Reset

**Anlass:** Die Lehrerin hat bei einer anderen Gruppe angemerkt, dass sich das RFID-Modul aufhängen kann.

**Ergebnis**
- 💬 **Rückfrage der KI:** manuell, automatisch oder gar nicht? Unsere Entscheidung: nur manuell
- Taste <kbd>B</kbd> im Zustand Unscharf startet den Leser neu und prüft danach, ob er wieder antwortet (OK- oder Fehlerton)
- Reine Software-Lösung, die Reset-Leitung war schon verdrahtet

> [!WARNING]
> **Offen:** am echten Aufbau testen, ob <kbd>B</kbd> einen hängenden Leser wirklich wiederbelebt.

<sub>🔗 [Vollständiger Eintrag](https://github.com/BBZ-AIFS51/LF7-Projekt_GAS/blob/main/MDs/entwicklungsverlauf.md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)</sub>

---

## 📆 23.09.2026 · README, 3D-Modell und Gehäuse

### 🎨 Schritt 8 — 3D-Animationen und neue README

**Anlass:** Das Repository einer befreundeten Gruppe ([LF7-MiniCasino](https://github.com/BBZ-AIFS51/LF7-MiniCasino)) hatte animierte 3D-Grafiken. So etwas wollten wir auch.

**Ergebnis**
- Drei animierte SVG-Grafiken für die README: Banner, Zustandsautomat, Verdrahtung
- **Interaktives 3D-Modell** im Browser (three.js). Die Firmware-Logik ist nach JavaScript übertragen, Tasten, Karten und Bewegungsmelder sind anklickbar.
- Veröffentlichung über GitHub Pages, README komplett neu

<p align="center">Animierter Zustandsautomat aus der README</p>

<sub>▶ [3D-Modell öffnen](https://bbz-aifs51.github.io/LF7-Projekt_GAS/) · 🔗 [Vollständiger Eintrag](https://github.com/BBZ-AIFS51/LF7-Projekt_GAS/blob/main/MDs/entwicklungsverlauf.md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)</sub>

### 🎨 Schritt 9 — README, Grafiken und 3D-Modell auf Englisch

**Wir wollten:** README und 3D-Modell auf Englisch, damit das Repository auch international verständlich ist.

**Ergebnis**
- README, alle drei SVG-Grafiken und die komplette Oberfläche des 3D-Modells übersetzt
- Die deutschen Dokumente bleiben deutsch und sind in der README als „(German)“ markiert

<sub>🔗 [Vollständiger Eintrag](https://github.com/BBZ-AIFS51/LF7-Projekt_GAS/blob/main/MDs/entwicklungsverlauf.md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)</sub>

### 📦 Schritt 10 — Gehäuse für den 3D-Druck

**Wir wollten:** ein Gehäuse für den 3D-Druck, ohne Vorerfahrung. Der Bewegungsmelder muss auf der anderen Seite der Tür sitzen, damit er nicht schon beim Entsperren auslöst.

**Ergebnis**
- **Zwei Gehäuse, ein Kabel:** Bedienteil außen (90 × 176 × 45 mm), Sensorteil innen. Der Bewegungsmelder sieht nicht durch die Wand.
- Parametrisches OpenSCAD-Modell, alle Maße als Variablen
- Druckteile ohne Stützstrukturen, dazu eine Einsteiger-Anleitung: Nachmessen, Slicen, Einkaufsliste, Zusammenbau

> [!WARNING]
> **Offen:** Die Modulmaße stammen aus Datenblättern und sind nicht nachgemessen. Gedruckt ist noch nichts.

<sub>📄 [`gehaeuse.md`](https://github.com/BBZ-AIFS51/LF7-Projekt_GAS/blob/main/MDs/gehaeuse.md) · 🔗 [Vollständiger Eintrag](https://github.com/BBZ-AIFS51/LF7-Projekt_GAS/blob/main/MDs/entwicklungsverlauf.md#10-prompt--gehäuse-für-den-3d-druck-23092026)</sub>

---

## 📆 29.09.2026 · Der Sensor dreht sich zur Tür

### 📦 Schritt 11 — Sensor schräg zur Tür

**Wir wollten:** Der Sensor soll leicht angewinkelt sitzen und den ganzen Eingang abdecken.

**Ergebnis**
- Neues Druckteil: **Keil mit 30°**, auf den das Sensorteil geschraubt wird
- Montageskizze angepasst, das Türscharnier liegt jetzt auf der anderen Seite (sonst stünde die offene Tür im Sichtfeld)

<sub>🔗 [Vollständiger Eintrag](https://github.com/BBZ-AIFS51/LF7-Projekt_GAS/blob/main/MDs/entwicklungsverlauf.md#11-prompt--sensor-schräg-zur-tür-29092026)</sub>

### 📦 Schritt 12 — Sensor noch stärker zur Tür

**Wir wollten:** noch mehr Abdeckung der Tür. Der Erfassungsbereich soll sich stark mit der Wand überschneiden.

**Ergebnis**
- Keil von 30° auf **60°**. Die türseitige Kante des Erfassungsbereichs läuft jetzt ca. 25° in die Wand hinein.

<table>
  <tr>
    <td align="center" width="50%">Montage von oben mit Erfassungsbereich<br><sub>Draufsicht: Erfassungsbereich</sub></td>
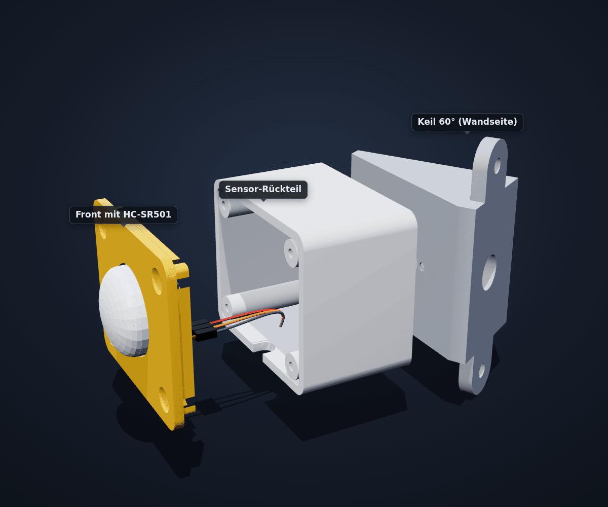
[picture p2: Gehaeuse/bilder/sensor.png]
Sensorteil auf dem 60-Grad-Keil
    <td align="center" width="50%"><br><sub>Sensorteil auf dem 60°-Keil</sub></td>
  </tr>
</table>

<sub>🔗 [Vollständiger Eintrag](https://github.com/BBZ-AIFS51/LF7-Projekt_GAS/blob/main/MDs/entwicklungsverlauf.md#12-prompt--sensor-noch-stärker-zur-tür-29092026)</sub>

---

## 📆 30.09.2026 · Das Gehäuse kommt ins 3D-Modell

### 🎨 Schritt 13 — Vorschaubilder, Gehäuse im 3D-Modell, Social Preview

**Wir wollten:** schönere Vorschaubilder, das Gehäuse im 3D-Modell (durchsichtig oder umschaltbar) und ein Vorschaubild für GitHub.

**Ergebnis**
- Neuer Tab **Enclosure** im 3D-Modell, gebaut aus den echten STL-Dateien. Das Gehäuse lässt sich massiv, durchsichtig oder ausgeblendet zeigen und aufklappen.
- Alle Gehäusebilder neu gerendert, dazu ein neues Bild der Druckplatte
- Social Preview im GitHub-Format (1280 × 640 px)

<sub>▶ [Enclosure-Tab öffnen](https://bbz-aifs51.github.io/LF7-Projekt_GAS/#enclosure) · 🔗 [Vollständiger Eintrag](https://github.com/BBZ-AIFS51/LF7-Projekt_GAS/blob/main/MDs/entwicklungsverlauf.md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äuse-im-3d-viewer-social-preview-30092026)</sub>

### 🎨 Schritt 14 — Banner und Social Preview mit Gehäuse

**Wir wollten:** Auch Banner und Social Preview sollen das Gerät im Gehäuse zeigen.

**Ergebnis**
- Das Banner zeigt das Bedienteil im Gehäuse und daneben das Sensorteil auf dem Keil, die Animation läuft wie vorher
- Social Preview mit massivem Gehäuse

<sub>🔗 [Vollständiger Eintrag](https://github.com/BBZ-AIFS51/LF7-Projekt_GAS/blob/main/MDs/entwicklungsverlauf.md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äuse-30092026)</sub>

### 🎨 Schritt 15 — Holo-Look für Banner und Social Preview

**Wir wollten:** das Gehäuse durchsichtig zeigen, wie im X-ray-Modus des 3D-Modells.

**Ergebnis**
- Das Banner ist jetzt ein Render aus dem 3D-Modell mit durchsichtigem Gehäuse. Die Animation liegt als eigene Ebene passgenau darüber.
- Das Banner wird per Skript erzeugt (`node tools/render.mjs banner`)

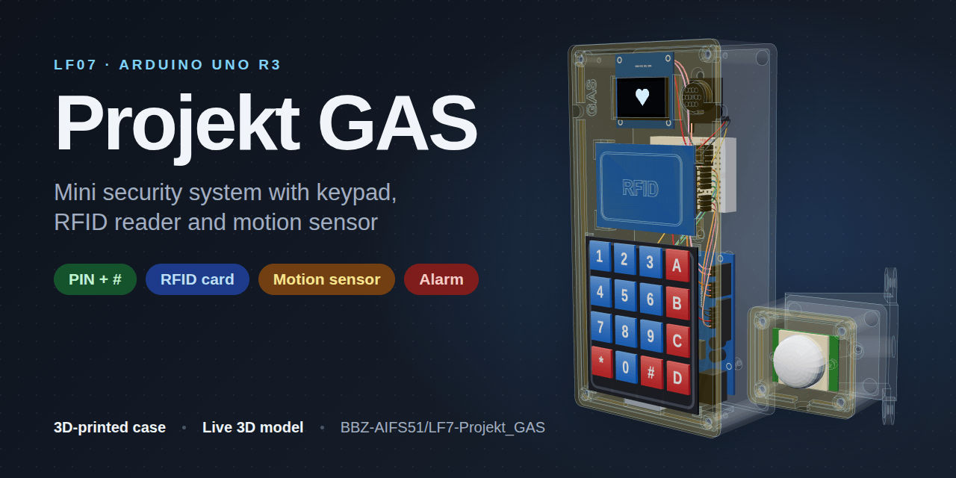
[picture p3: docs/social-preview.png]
Social Preview im Holo-Look


<sub>🔗 [Vollständiger Eintrag](https://github.com/BBZ-AIFS51/LF7-Projekt_GAS/blob/main/MDs/entwicklungsverlauf.md#15-prompt--holo-look-für-banner-und-social-preview-30092026)</sub>

---

## 📆 06.10.2026 · Feinschliff und Wiki

### 🐞 Schritt 16 — Falsche Eingabe bricht den Alarm ab

**Problem:** Gibt man während des Alarms eine falsche PIN ein oder hält eine falsche Karte vor, kommt kurz der Fehlerton, danach ist die Sirene aus.

**Ergebnis**
- **Ursache:** Der Fehlerton hat die Sirene ersetzt. Nach seinem Ende war Stille, obwohl die Anlage noch im Alarm war.
- **Fix:** Während des Alarms werden falsche Eingaben ignoriert. Nur die richtige PIN oder eine bekannte Karte beendet ihn.
- Das 3D-Modell verhält sich gleich (Logik dort mitgezogen)

> [!WARNING]
> **Offen:** nicht kompiliert und nicht am Aufbau getestet.

<sub>🔗 [Vollständiger Eintrag](https://github.com/BBZ-AIFS51/LF7-Projekt_GAS/blob/main/MDs/entwicklungsverlauf.md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)</sub>

### 📝 Schritt 17 — Projekt-Wiki

**Wir wollten:** die Wiki-Seite des Repositorys sinnvoll nutzen: erst Vorschläge, dann ein Plan, dann die Umsetzung als saubere Projektdokumentation.

**Ergebnis**
- Dieses Wiki: 8 Seiten mit Seitenleiste und Fußzeile
- Diagramme direkt im Wiki (Mermaid): Zeitleiste, Gantt, Zustandsautomat, Systemüberblick
- Platzhalter (✏️ TODO) für alles, was nur das Team wissen kann: Team, Kosten, Fotos, Reflexion

<sub>🔗 [Vollständiger Eintrag](https://github.com/BBZ-AIFS51/LF7-Projekt_GAS/blob/main/MDs/entwicklungsverlauf.md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)</sub>

### 📝 Schritt 18 — Doku nach den Vorgaben der Lehrkraft

**Anlass:** Die Vorgaben für Projektdokumentation und Präsentation lagen vor: zehn feste Kapitel, und Prompts werden nicht in der Dokumentation abgedruckt.

**Ergebnis**
- Wiki nach den zehn Kapiteln umgebaut. Neu: Funktionsbeschreibung, Verwendete Bauteile, Aufbau und Schaltplan, Sourcecode, Wichtige Codeabschnitte, Herausforderungen, Quellenverzeichnis. Planung, Kosten und Verlauf stehen jetzt im Anhang.
- Prompts im Wortlaut aus dem Wiki entfernt, die Karten auf dieser Seite heißen jetzt „Schritt“
- Vorschlag, wie die gesamte Abgabe und die Präsentation aussehen können
- Nebenbei korrigiert: Am Uno ist neben D0/D1 auch A3 noch frei

> [!WARNING]
> **Offen:** mit der Lehrkraft klären, ob das Arbeitsprotokoll im Repository (enthält die Prompts im Wortlaut) als Anhang in Ordnung ist.

<sub>🔗 [Vollständiger Eintrag](https://github.com/BBZ-AIFS51/LF7-Projekt_GAS/blob/main/MDs/entwicklungsverlauf.md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)</sub>

### 📝 Schritt 19 — Wiki automatisch veröffentlichen

**Problem:** Die Wiki-Seiten mussten bisher als ZIP heruntergeladen und von Hand ins Wiki hochgeladen werden.

**Ergebnis**
- Die Wiki-Seiten liegen jetzt im Repository im Ordner [`wiki/`](https://github.com/BBZ-AIFS51/LF7-Projekt_GAS/tree/main/wiki)
- Ein GitHub-Workflow überträgt den Ordner bei jedem Push nach `main` automatisch ins Wiki
- Bearbeitet wird nur noch in `wiki/`, Änderungen im Wiki-Editor werden überschrieben

<sub>⚙️ [`wiki.yml`](https://github.com/BBZ-AIFS51/LF7-Projekt_GAS/blob/main/.github/workflows/wiki.yml) · 🔗 [Vollständiger Eintrag](https://github.com/BBZ-AIFS51/LF7-Projekt_GAS/blob/main/MDs/entwicklungsverlauf.md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öffentlichen-06102026)</sub>

---

<p align="center"><sub>Wie wir mit der KI gearbeitet haben und was wir selbst geprüft haben: <a href="KI-Einsatz">🤖 KI-Einsatz</a></sub></p>

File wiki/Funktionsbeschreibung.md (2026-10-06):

<!-- Diese Seite wird automatisch aus dem Ordner wiki/ im Repository erzeugt. Änderungen im Wiki-Editor werden beim nächsten Abgleich überschrieben. Bearbeiten: https://github.com/BBZ-AIFS51/LF7-Projekt_GAS/tree/main/wiki -->
# 3 · 🎛️ Funktionsbeschreibung

Wie die fertige Anlage aus Sicht der Anwender funktioniert und wie die Bauteile
dabei zusammenspielen. Wie das im Code umgesetzt ist, steht in
[Kapitel 7](Wichtige-Codeabschnitte).

## Einsatzort

Die Anlage besteht aus zwei Teilen. Das **Bedienteil** mit Tastenfeld, Display,
Kartenleser und Buzzer hängt außen neben der Tür. Das **Sensorteil** mit dem
Bewegungsmelder sitzt innen im Raum und schaut auf den Eingang. Weil der Sensor
nicht durch die Wand sieht, löst niemand Alarm aus, der draußen am Tastenfeld
steht. Erst wer den Raum betritt, wird erkannt.

<p align="center">
  Montage von oben: Bedienteil außen, Sensorteil innen, Erfassungsbereich deckt den Eingang ab<br>
  <sub>Montage von oben: Der Erfassungsbereich des Sensors deckt den Eingang ab</sub>
</p>

## Die Anlage im Alltag

| # | Situation | Was die Person tut | Was die Anlage macht |
|:---:|---|---|---|
| 1 | Die Anlage ist **unscharf** | – | Display zeigt ein ❤️ Herz. Bewegung im Raum wird ignoriert. |
| 2 | Den Raum verlassen | PIN eintippen und mit <kbd>#</kbd> bestätigen **oder** Karte an den Leser halten | Heller Doppelton, Display zeigt 💀 und einen Countdown. 10 Sekunden lang piept es jede Sekunde: Zeit, den Raum zu verlassen. |
| 3 | Die Anlage ist **scharf** | – | Display zeigt dauerhaft 💀. Der Bewegungsmelder ist aktiv. |
| 4 | Jemand betritt den Raum | – | **Alarm:** schrille Sirene, das Display blinkt mit 💀 und zeigt die Restzeit. Nach 30 Sekunden ist die Sirene aus, die Anlage bleibt scharf. |
| 5 | Zurückkommen | PIN + <kbd>#</kbd> oder Karte | Heller Doppelton, ❤️ Herz: wieder unscharf. Ein laufender Alarm wird damit sofort beendet. |
| 6 | Falsche PIN oder unbekannte Karte | – | Rauer, tiefer Brummton, Display zeigt kurz ein ✖. |
| 7 | **3 Fehlversuche** hintereinander | – | Sofort Alarm, auch wenn die Anlage gerade unscharf war. |
| 8 | Falsche Eingabe während des Alarms | – | Wird ignoriert, die Sirene läuft weiter. Nur die richtige PIN oder eine bekannte Karte beendet den Alarm. |

> [!TIP]
> Die PIN erscheint beim Tippen nur als `*`. Eine halb getippte PIN verschwindet
> nach 10 Sekunden ohne Tastendruck von selbst, mit <kbd>*</kbd> lässt sie sich
> sofort löschen.

## Zustände der Anlage

Die Anlage ist immer in genau einem von fünf Zuständen. Was eine Eingabe
bewirkt, hängt vom aktuellen Zustand ab.

```mermaid
stateDiagram-v2
    [*] --> Unscharf
    Unscharf --> Ausgangsverzögerung: PIN oder Karte
    Ausgangsverzögerung --> Scharf: nach 10 s
    Ausgangsverzögerung --> Unscharf: PIN oder Karte
    Scharf --> Alarm: Bewegung
    Scharf --> Unscharf: PIN oder Karte
    Alarm --> Unscharf: PIN oder Karte
    Alarm --> Scharf: nach 30 s
    Unscharf --> Admin: A + Admin-PIN
    Admin --> Unscharf: * oder 20 s Leerlauf

    Unscharf: ❤️ Unscharf
    Ausgangsverzögerung: 💀 Ausgangsverzögerung (Piepen)
    Scharf: 💀 Scharf
    Alarm: 💀 ALARM (Sirene, Display blinkt)
    Admin: 📋 Admin-Menü
```

Außerhalb des Alarms gilt: **3 falsche Eingaben** (PIN, Admin-PIN oder
unbekannte Karte) lösen sofort den Alarm aus.

## Rückmeldungen

Das Display zeigt bewusst keinen Text, sondern Symbole. Zusammen mit den Tönen
ist auf einen Blick klar, was gerade passiert.

| Ereignis | Display | Ton |
|---|---|---|
| Unscharf | ❤️ Herz | – |
| Ausgangsverzögerung | 💀 Totenkopf + Countdown | kurzer Piep jede Sekunde |
| Scharf | 💀 Totenkopf | – |
| Alarm | 💀 Totenkopf, ganzer Bildschirm blinkt, Countdown | Sirene, auf- und abschwellend |
| Taste gedrückt | `*` pro Ziffer | kurzer Klick |
| Richtige PIN oder bekannte Karte | neues Symbol | heller Doppelton |
| Falsche PIN oder unbekannte Karte | ✖ | rauer, tiefer Brummton |

## Karten verwalten (Admin-Menü)

Welche Karten die Anlage schalten dürfen, wird direkt am Gerät festgelegt, ganz
ohne PC. Die Karten bleiben gespeichert, auch wenn der Strom weg ist.

1. Anlage ist unscharf: <kbd>A</kbd> drücken, Admin-PIN eintippen, <kbd>#</kbd>.
2. Im Menü:
   - <kbd>1</kbd> **Karte anlernen:** neue Karte an den Leser halten. Das Display meldet *Saved*, *Known* (schon gespeichert) oder *Full* (8 Karten erreicht).
   - <kbd>2</kbd> **Karten anzeigen:** mit <kbd>#</kbd> blättern, mit <kbd>D</kbd> die angezeigte Karte löschen.
   - <kbd>*</kbd> zurück bzw. Menü verlassen. Nach 20 Sekunden ohne Eingabe schließt das Menü von selbst.

Eine falsche Admin-PIN zählt als Fehlversuch, genau wie eine falsche normale PIN.

## Tastenbelegung

| Taste | Wirkung |
|---|---|
| <kbd>0</kbd> … <kbd>9</kbd> | PIN eingeben (Anzeige nur als `*`) |
| <kbd>#</kbd> | Eingabe bestätigen |
| <kbd>*</kbd> | Eingabe löschen · im Admin-Menü: zurück |
| <kbd>A</kbd> | im Zustand UNSCHARF: Admin-Menü (danach Admin-PIN + <kbd>#</kbd>) |
| <kbd>B</kbd> | im Zustand UNSCHARF: RFID-Leser neu starten, falls er hängt |
| <kbd>C</kbd> | ohne Funktion |
| <kbd>D</kbd> | im Admin-Menü: angezeigte Karte löschen |
| 💳 Karte | wirkt wie die richtige PIN, wenn sie gespeichert ist |

## Zusammenspiel der Bauteile

Der Arduino fragt die drei Eingaben ständig reihum ab, entscheidet im
Zustandsautomaten und steuert die zwei Ausgaben. Die erlaubten Karten liegen im
internen EEPROM des Arduino.

```mermaid
flowchart LR
    subgraph IN["Eingaben"]
        K["⌨️ Keypad 4x4"]
        R["📶 RFID-Leser RC522"]
        P["👁️ Bewegungsmelder HC-SR501"]
    end
    U(["🧠 Arduino Uno R3<br/>Zustandsautomat"])
    E[("💾 EEPROM<br/>gespeicherte Karten")]
    subgraph OUT["Ausgaben"]
        O["🖥️ OLED 1,3 Zoll"]
        B["🔊 Passiver Buzzer"]
    end
    K -- "Matrix-Scan" --> U
    R -- "SPI" --> U
    P -- "digital" --> U
    U -- "I²C" --> O
    U -- "tone()" --> B
    U <--> E
```

Die ausführliche Bedienungsanleitung für Endanwender gibt es als
[PDF](https://github.com/BBZ-AIFS51/LF7-Projekt_GAS/blob/main/Anleitung/Mini%20Security%20System%20Manual.pdf).
Ausprobieren lässt sich alles auch ohne Gerät im
[3D-Modell](https://bbz-aifs51.github.io/LF7-Projekt_GAS/): Dort läuft die
gleiche Logik wie in der Firmware.

---

<sub>← [2 Idee und Zielsetzung](Idee-und-Zielsetzung) · [4 Verwendete Bauteile](Verwendete-Bauteile) →</sub>

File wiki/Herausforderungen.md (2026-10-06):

<!-- Diese Seite wird automatisch aus dem Ordner wiki/ im Repository erzeugt. Änderungen im Wiki-Editor werden beim nächsten Abgleich überschrieben. Bearbeiten: https://github.com/BBZ-AIFS51/LF7-Projekt_GAS/tree/main/wiki -->
# 8 · 🧗 Herausforderungen

Bei welchen Bauteilen und Arbeitsschritten es Schwierigkeiten gab oder etwas
Besonderes zu beachten war, was die Ursache war und wie wir das Problem gelöst
haben.

| Bauteil / Bereich | Problem | Lösung in einem Satz |
|---|---|---|
| 🖥️ Display | [Display bleibt leer](#oled-display-bleibt-leer) | richtige Library für den SH1106 |
| 🧠 Arduino | [Arbeitsspeicher zu knapp](#arbeitsspeicher-zu-knapp) | Texte in den Flash, Keypad selbst abfragen |
| 📶 RFID + 👁️ Bewegungsmelder | [Zwei Bauteile, ein Pin](#zwei-bauteile-ein-pin) | Bewegungsmelder auf A2 umgezogen |
| 📶 RFID + 🔊 Buzzer | [Buzzer-Pin nach dem Start auf HIGH](#buzzer-pin-nach-dem-start-auf-high) | Reihenfolge in `setup()` getauscht |
| 📶 RFID | [Tastenfeld träge, Sirene stockt](#tastenfeld-träge-sirene-stockt) | Kartenleser nur alle 200 ms abfragen |
| 📶 RFID | [Kartenleser antwortet nicht mehr](#kartenleser-antwortet-nicht-mehr) | Neustart des Lesers per Taste <kbd>B</kbd> |
| 📶 RFID | [Versorgungsspannung](#versorgungsspannung-des-rfid-lesers) | 3,3 V statt 5 V |
| 🔊 Alarm | [Falsche Eingabe beendet den Alarm](#falsche-eingabe-beendet-den-alarm) | falsche Eingaben im Alarm ignorieren |
| 📦 Gehäuse | [Wohin mit dem Bewegungsmelder?](#wohin-mit-dem-bewegungsmelder) | eigenes Sensorteil im Raum, auf einem 60°-Keil |

---

### OLED-Display bleibt leer

**Zu beachten:** Fast alle Anleitungen für 128x64-OLEDs gehen von einem
anderen Display-Controller aus. Mit deren Beispielcode bleibt unser Display
leer oder zeigt nur Streifen.

**Ursache:** Die meisten Anleitungen verwenden die Library für den
Display-Controller SSD1306. Unser 1,3-Zoll-Display hat aber einen **SH1106**.
Beide sehen gleich aus, werden aber unterschiedlich angesteuert.

**Lösung:** Beim ersten Test am Aufbau ermittelt, welcher Controller verbaut
ist, danach die Library *Adafruit SH110X* mit der Klasse `Adafruit_SH1106G`
verwendet.

> [!NOTE]
> ✏️ **TODO (Team):** Kurz ergänzen, wie ihr den SH1106 erkannt habt (Aufdruck,
> Datenblatt des Händlers, Ausprobieren?).

### Arbeitsspeicher zu knapp

**Situation:** Mit der ersten Firmware zeigte das Display Pixelmüll statt Herz
und Totenkopf. Nach einer Verbesserung lief es, aber nach einmal Scharf- und
Unscharfschalten wurde die richtige PIN plötzlich als falsch erkannt.

**Ursache:** Der Uno hat 2048 Byte Arbeitsspeicher, das Display belegt davon
allein 1024 Byte. Im seriellen Monitor stand nur noch `free SRAM: 205`, und eine
Ausgabe brach mitten im Wort ab, gefolgt von der Startmeldung. Der Arduino
startete also neu, weil der Speicher überlief.

**Lösung:** In zwei Schritten Speicher gespart:
1. Alle Texte mit `F()` im Flash-Speicher abgelegt, kein `snprintf`, keine
   Textpuffer.
2. Die Keypad-Library (ca. 120 Byte) durch eine eigene Abfrage der Tastenmatrix
   ersetzt, siehe [Kapitel 7.5](Wichtige-Codeabschnitte#75-tastenfeld-selbst-abfragen).

Seitdem gibt die Firmware beim Start den freien Speicher aus, um das im Blick zu
behalten.

### Zwei Bauteile, ein Pin

**Situation:** Der Bewegungsmelder hing an D11. Als der RFID-Leser dazukam,
brauchte der ebenfalls D11.

**Ursache:** Der RFID-Leser kommuniziert über SPI. Beim Uno liegen die
SPI-Leitungen fest auf D11, D12 und D13, sie lassen sich nicht verlegen.

**Lösung:** Der Bewegungsmelder ist auf **A2** umgezogen. Die analogen Pins des
Uno lassen sich auch als normale Digitalpins verwenden.

### Buzzer-Pin nach dem Start auf HIGH

**Zu beachten:** Beim Einbau des RFID-Lesers kam eine versteckte
Wechselwirkung mit dem Buzzer dazu.

**Ursache:** `SPI.begin()` schaltet D10 automatisch auf Ausgang mit HIGH, weil
D10 beim Uno der feste SS-Pin für SPI ist. Genau dort hängt aber der Buzzer.

**Lösung:** In `setup()` zuerst `SPI.begin()` aufrufen und **erst danach** den
Buzzer-Pin auf LOW setzen. So startet der Buzzer immer in einem definierten,
stillen Zustand.

### Tastenfeld träge, Sirene stockt

**Zu beachten:** Der RFID-Leser darf nicht bei jedem Durchlauf von `loop()`
abgefragt werden, sonst reagiert das Tastenfeld langsamer und die Sirene klingt
abgehackt.

**Ursache:** Liegt keine Karte auf, wartet eine Abfrage des Lesers etwa 25 ms
auf eine Antwort, die nie kommt. Bei jeder Runde von `loop()` summiert sich das.

**Lösung:** Der Leser wird nur noch alle 200 ms abgefragt. Eine Karte wird
trotzdem sofort erkannt, das Tastenfeld bleibt flüssig.

### Kartenleser antwortet nicht mehr

**Situation:** Die Lehrkraft hat darauf hingewiesen, dass sich RC522-Module
öfter aufhängen. Dann werden Karten plötzlich nicht mehr gelesen, und es hilft
nur, den ganzen Arduino neu zu starten.

**Ursache:** Günstige Nachbauten des RC522 hängen sich manchmal auf und
antworten dann nicht mehr über SPI.

**Lösung:** Auf Anregung der Lehrkraft startet Taste <kbd>B</kbd> (im
unscharfen Zustand) nur den Leser neu und prüft danach, ob er wieder antwortet.
Ein heller Ton heißt: Leser ist wieder da.

### Versorgungsspannung des RFID-Lesers

**Zu beachten:** Alle anderen Module laufen mit 5 V. Der RFID-Leser darf das nicht.

**Ursache:** Der Chip des RC522 ist für 3,3 V gebaut, 5 V zerstören das Modul.

**Lösung:** VCC des Lesers an den 3,3-V-Pin des Uno. Der liefert bis zu 50 mA,
der Leser braucht etwa 13–26 mA. Die Datenleitungen kommen weiter mit 5 V vom
Uno. Laut Datenblatt ist das außerhalb der Spezifikation, funktioniert in der
Praxis aber zuverlässig.

> [!NOTE]
> ✏️ **TODO (Team):** Gab es Probleme beim Verdrahten des Lesers (z. B. falsche
> Pins, lose Kabel)? Der Test-Sketch `rfid_test` zeigt die Version des Lesers:
> `0x91` oder `0x92` heißt „läuft“, `0x00` oder `0xFF` heißt „antwortet nicht“.

### Falsche Eingabe beendet den Alarm

**Situation:** Beim Testen ist aufgefallen: Wer während des Alarms eine falsche
PIN eingab oder eine falsche Karte vorhielt, hörte kurz den Fehlerton. Danach
war die Sirene aus.

**Ursache:** Es kann immer nur ein Ton gleichzeitig laufen. Der Fehlerton hat die
Sirene ersetzt, und nach seinem Ende war Stille, obwohl die Anlage noch im Alarm
war.

**Lösung:** Während des Alarms werden falsche Eingaben ignoriert. Nur die
richtige PIN oder eine bekannte Karte beendet ihn, siehe
[Kapitel 7.3](Wichtige-Codeabschnitte#73-zugriff-erlaubt-oder-verweigert).

### Wohin mit dem Bewegungsmelder?

**Situation:** Sitzt der Bewegungsmelder im selben Gehäuse wie das Tastenfeld,
sieht er die Person, die gerade die PIN eintippt.

**Lösung:** Zwei Gehäuse: Das Bedienteil hängt außen, das Sensorteil innen. Die
Wand liegt dazwischen, deshalb sieht der Sensor die Person am Tastenfeld nicht.
Flach an der Wand hätte der Sensor allerdings geradeaus in den Raum geschaut und
die Tür nur am Rand erfasst. Ein Keil dreht ihn zur Tür. Zuerst waren es 30°.
Damit die Tür sicher erfasst wird, haben wir auf 60° erhöht: Jetzt reicht der
Erfassungsbereich auf der Türseite bis in die Wand hinein und deckt den ganzen
Eingang ab.

<p align="center">
  Sensorteil auf dem 60°-Keil
</p>

---

## Weitere Herausforderungen

> [!NOTE]
> ✏️ **TODO (Team):** Ergänzt Probleme, die nur ihr kennt, zum Beispiel:
> - Verdrahtung auf dem Breadboard: Wackelkontakte, vertauschte Kabel?
> - Bewegungsmelder: Empfindlichkeit und Haltezeit an den Potis einstellen,
>   Fehlalarme? Nach dem Einschalten braucht er etwa eine Minute, bis er
>   zuverlässig arbeitet.
> - 3D-Druck: Passte alles? Was musste nachgearbeitet werden?
> - Zusammenarbeit, Zeitplanung, Git
>
> Gleiches Schema: **Situation**, **Ursache**, **Lösung**.

---

<sub>← [7 Wichtige Codeabschnitte](Wichtige-Codeabschnitte) · [9 Fazit und Ausblick](Fazit-und-Ausblick) →</sub>

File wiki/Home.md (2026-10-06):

<!-- Diese Seite wird automatisch aus dem Ordner wiki/ im Repository erzeugt. Änderungen im Wiki-Editor werden beim nächsten Abgleich überschrieben. Bearbeiten: https://github.com/BBZ-AIFS51/LF7-Projekt_GAS/tree/main/wiki -->
<p align="center">
  Projekt GAS: Mini-Sicherheitssystem mit Keypad, RFID-Leser und Bewegungsmelder
</p>

<p align="center">
  
  
  
  
</p>

# Projekt GAS – Mini-Sicherheitssystem

<p align="center"><b>Projektdokumentation · Lernfeld 7</b></p>

| | |
|---|---|
| **Projekttitel** | Projekt GAS – Mini-Sicherheitssystem mit Keypad, RFID-Leser und Bewegungsmelder |
| **Gruppenmitglieder** | ✏️ TODO (Team): Vor- und Nachnamen |
| **Klasse** | ✏️ TODO (Team) |
| **Lehrkraft** | ✏️ TODO (Team) |
| **Datum der Abgabe** | ✏️ TODO (Team) |

Eine kleine Alarmanlage auf einem Arduino Uno R3, gebaut im Lernfeld 7. Scharf-
und unscharf geschaltet wird mit einer PIN am 4x4-Keypad oder mit einer
RFID-Karte. Ist die Anlage scharf, löst der Bewegungsmelder eine 30-sekündige
Sirene aus. Das OLED zeigt nur Symbole: ein Herz (unscharf), einen Totenkopf
(scharf) und einen blinkenden Totenkopf (Alarm). Karten werden direkt am Gerät
angelernt, ganz ohne PC(Computer).

> [!NOTE]
> ✏️ **TODO (Team):** Hier ein Foto oder GIF vom fertigen Gerät einfügen
> (z. B. Karte auflegen → Herz wird zum Totenkopf). Bild im Repository unter
> `wiki/images/` ablegen und so einbinden:
> `<p align="center"><img src="https://raw.githubusercontent.com/BBZ-AIFS51/LF7-Projekt_GAS/main/wiki/images/geraet.gif" width="60%"></p>`

<p align="center">
  <a href="https://bbz-aifs51.github.io/LF7-Projekt_GAS/"><b>▶ 3D-Modell im Browser ausprobieren</b></a>
  &nbsp;·&nbsp; <a href="https://github.com/BBZ-AIFS51/LF7-Projekt_GAS">Repository mit Sourcecode</a>
  &nbsp;·&nbsp; <a href="https://github.com/BBZ-AIFS51/LF7-Projekt_GAS/blob/main/Anleitung/Mini%20Security%20System%20Manual.pdf">Bedienungsanleitung (PDF)</a>
</p>

## Inhalt

Die Kapitel 1–10 folgen dem vorgegebenen Aufbau der Projektdokumentation. Der
Anhang enthält Planung, Kosten und den Verlauf der Entwicklung.

| Kapitel | Worum es geht |
|---|---|
| **1** Deckblatt | diese Seite |
| **2** [💡 Idee und Zielsetzung](Idee-und-Zielsetzung) | Welches Problem das Projekt löst, Anforderungen, Abgrenzung |
| **3** [🎛️ Funktionsbeschreibung](Funktionsbeschreibung) | Wie die Anlage aus Sicht der Anwender funktioniert |
| **4** [🧩 Verwendete Bauteile](Verwendete-Bauteile) | Alle Bauteile und wofür sie eingesetzt werden |
| **5** [🔌 Aufbau und Schaltplan](Aufbau-und-Schaltplan) | Schaltplan, Pin-Zuordnung, Foto vom Aufbau, Gehäuse |
| **6** [📄 Sourcecode](Sourcecode) | Welche Dateien zum Projekt gehören |
| **7** [🧠 Wichtige Codeabschnitte](Wichtige-Codeabschnitte) | Kernlogik der Firmware, erklärt |
| **8** [🧗 Herausforderungen](Herausforderungen) | Probleme mit Bauteilen und wie wir sie gelöst haben |
| **9** [💭 Fazit und Ausblick](Fazit-und-Ausblick) | Was wir gelernt haben, mögliche Erweiterungen |
| **10** [📚 Quellenverzeichnis](Quellenverzeichnis) | Datenblätter, Bibliotheken, Werkzeuge |

| Anhang | Worum es geht |
|---|---|
| [👥 Team und Rollen](Team-und-Rollen) | Wer hat was gemacht |
| [📅 Zeitplan](Zeitplan) | Geplanter und tatsächlicher Ablauf |
| [💶 Kosten](Kosten) | Preise und Gesamtkosten |
| [🔧 Projektphasen](Projektphasen) | Die sieben Phasen des Projekts, Stand und offene Punkte |
| [🧭 Entwicklungsverlauf](Entwicklungsverlauf) | Alle Arbeitsschritte als Zeitleiste |
| [🤖 KI-Einsatz](KI-Einsatz) | Wie wir Claude Code als Hilfsmittel eingesetzt haben |

## Auf einen Blick

| **6** | **4** | **19** | **5** | **5** |
|:---:|:---:|:---:|:---:|:---:|
| Bauteile am Uno | Arduino-Sketches | Arbeitsschritte im [Entwicklungsverlauf](Entwicklungsverlauf) | Zustände der Anlage | Druckteile fürs Gehäuse |

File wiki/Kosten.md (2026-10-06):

<!-- Diese Seite wird automatisch aus dem Ordner wiki/ im Repository erzeugt. Änderungen im Wiki-Editor werden beim nächsten Abgleich überschrieben. Bearbeiten: https://github.com/BBZ-AIFS51/LF7-Projekt_GAS/tree/main/wiki -->
# 💶 Kosten

<sub>Anhang</sub>

Alle Bauteile und Materialien mit Preis. Grundlage sind die Hardware-Tabelle
im [README](https://github.com/BBZ-AIFS51/LF7-Projekt_GAS#hardware) und die
Einkaufsliste in der [Gehäuse-Anleitung](https://github.com/BBZ-AIFS51/LF7-Projekt_GAS/blob/main/MDs/gehaeuse.md#schritt-4--einkaufsliste).

> [!IMPORTANT]
> ✏️ **TODO (Team):** Preise und Bezugsquellen eintragen. Was von der Schule
> gestellt wurde, mit „gestellt“ markieren und trotzdem einen Richtpreis
> angeben, damit die Gesamtkosten aussagekräftig sind.
>
> Die [Teile.xlsx](https://github.com/BBZ-AIFS51/LF7-Projekt_GAS/blob/main/Teile.xlsx)
> im Repository enthält bisher nur Uno, Bewegungsmelder und Keypad. Am besten
> dort vervollständigen und hier die Übersicht pflegen.

## Elektronik

| Anz. | Bauteil | Hersteller / Typ | Bezugsquelle | Einzelpreis | Summe |
|:---:|---|---|---|---:|---:|
| 1 | Mikrocontroller | Arduino Uno R3 | ✏️ | ✏️ € | ✏️ € |
| 1 | Tastenfeld 4x4 | Folien-Keypad | ✏️ | ✏️ € | ✏️ € |
| 1 | OLED-Display 1,3", 128x64, I²C | Controller SH1106 | ✏️ | ✏️ € | ✏️ € |
| 1 | RFID-Leser mit Karte und Schlüsselanhänger | RC522 (13,56 MHz) | ✏️ | ✏️ € | ✏️ € |
| 1 | Bewegungsmelder (PIR) | Joy-IT SEN-HC-SR501 | ✏️ | ✏️ € | ✏️ € |
| 1 | Passiver Buzzer | ✏️ | ✏️ | ✏️ € | ✏️ € |
| 1 | Breadboard bzw. Mini-Breadboard (170 Kontakte) | ✏️ | ✏️ | ✏️ € | ✏️ € |
| 1 | Jumper-Kabel (Set) | ✏️ | ✏️ | ✏️ € | ✏️ € |
| 1 | Stromversorgung: 9-V-Batterie mit Hohlstecker oder USB-Netzteil 5 V | ✏️ | ✏️ | ✏️ € | ✏️ € |
| | | | | **Zwischensumme** | **✏️ €** |

## Gehäuse

| Anz. | Teil | Wofür | Bezugsquelle | Einzelpreis | Summe |
|:---:|---|---|---|---:|---:|
| ✏️ g | Filament (PLA) | 5 Druckteile | ✏️ | ✏️ €/kg | ✏️ € |
| 8 | Senkkopf-Schraube 3 × 12 mm | Frontplatten | ✏️ | | ✏️ € |
| 4 | Linsenkopf-Schraube 3 × 8 mm | Arduino Uno | ✏️ | | ✏️ € |
| 2 | Schraube M2 × 6 mm | Bewegungsmelder | ✏️ | | ✏️ € |
| 2 | Senkkopf-Schraube 3 × 10 mm | Sensor auf Keil | ✏️ | | ✏️ € |
| 4 | Holzschraube 3,5–4 mm mit Dübel | Wandmontage | ✏️ | | ✏️ € |
| 1 | 3-adriges Kabel mit Dupont-Steckern | Verbindung zum Sensorteil | ✏️ | | ✏️ € |
| | | | | **Zwischensumme** | **✏️ €** |

> [!TIP]
> Den Filamentverbrauch zeigt der Slicer nach dem Slicen an (in Gramm).
> Kosten = Gramm × Preis pro kg / 1000.

## Gesamtkosten

| Bereich | Kosten |
|---|---:|
| Elektronik | ✏️ € |
| Gehäuse | ✏️ € |
| **Gesamt** | **✏️ €** |

<!--
  Nach dem Ausfüllen: Den folgenden Block (ohne die Kommentarzeichen) hier
  einfügen und die Zahlen ersetzen. GitHub zeichnet daraus ein Tortendiagramm.

```mermaid
pie showData
    title Kostenverteilung in Euro
    "Arduino Uno" : 0
    "Display" : 0
    "RFID-Leser" : 0
    "Bewegungsmelder" : 0
    "Keypad und Buzzer" : 0
    "Kabel und Breadboard" : 0
    "Gehäuse" : 0
```
-->

> [!NOTE]
> ✏️ **TODO (Team):** Wenn die Preise feststehen, das vorbereitete
> Tortendiagramm einblenden. Es steht als Kommentar im Quelltext dieser Seite
> (im Repository in `wiki/Kosten.md` ganz unten).

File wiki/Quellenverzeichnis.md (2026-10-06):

<!-- Diese Seite wird automatisch aus dem Ordner wiki/ im Repository erzeugt. Änderungen im Wiki-Editor werden beim nächsten Abgleich überschrieben. Bearbeiten: https://github.com/BBZ-AIFS51/LF7-Projekt_GAS/tree/main/wiki -->
# 10 · 📚 Quellenverzeichnis

Verwendete Datenblätter, Dokumentationen, Bibliotheken und Werkzeuge.

> [!NOTE]
> ✏️ **TODO (Team):**
> - **Abrufdatum** prüfen und ggf. anpassen (alle Links zuletzt geprüft am 06.10.2026).
> - Ergänzen, was ihr selbst genutzt habt: Tutorials, Videos, Foren, Unterlagen
>   aus dem Unterricht.
> - Falls die Lehrkraft ein bestimmtes Zitierformat verlangt, die Einträge
>   entsprechend umstellen.

## Datenblätter

| # | Bauteil | Quelle |
|:---:|---|---|
| [1] | Arduino Uno R3 | Arduino: *UNO R3 – Product Reference Manual (A000066)*. https://docs.arduino.cc/resources/datasheets/A000066-datasheet.pdf |
| [2] | Arduino Uno R3 | Arduino: *UNO R3 – Dokumentation*. https://docs.arduino.cc/hardware/uno-rev3/ |
| [3] | Mikrocontroller ATmega328P | Microchip Technology: *ATmega328P – Produktseite und Datenblatt*. https://www.microchip.com/en-us/product/ATmega328P |
| [4] | RFID-Leser RC522 | NXP Semiconductors: *MFRC522 – Standard performance MIFARE and NTAG frontend*, Datenblatt. https://www.nxp.com/docs/en/data-sheet/MFRC522.pdf |
| [5] | OLED-Controller SH1106 | Sino Wealth: *SH1106 – 132 × 64 Dot Matrix OLED/PLED Segment/Common Driver with Controller*, Datenblatt. https://www.pololu.com/file/0J1813/SH1106.pdf |
| [6] | Bewegungsmelder HC-SR501 | Joy-IT: *SEN-HC-SR501 – Passive infrared motion sensor*, Produktseite mit Datenblatt. https://joy-it.net/en/products/SEN-HC-SR501 |
| [7] | Bewegungsmelder HC-SR501 | Handson Technology: *HC-SR501 PIR Motion Sensor*, Datenblatt. http://www.handsontec.com/dataspecs/SR501%20Motion%20Sensor.pdf |
| [8] | 4x4-Keypad, passiver Buzzer | ✏️ TODO (Team): Datenblatt bzw. Produktseite des Händlers |

## Arduino-Dokumentation

| # | Thema | Quelle |
|:---:|---|---|
| [9] | Sprachreferenz | Arduino: *Language Reference*. https://docs.arduino.cc/language-reference/ |
| [10] | Töne erzeugen | Arduino: *tone()*. https://docs.arduino.cc/language-reference/en/functions/advanced-io/tone/ |
| [11] | Töne stoppen | Arduino: *noTone()*. https://docs.arduino.cc/language-reference/en/functions/advanced-io/noTone/ |
| [12] | Daten im Flash ablegen | Arduino: *PROGMEM*. https://docs.arduino.cc/language-reference/en/variables/utilities/PROGMEM |
| [13] | Speicherarten (SRAM, Flash, EEPROM) | Arduino: *Arduino Memory Guide*. https://www.arduino.cc/en/Tutorial/Memory |

## Bibliotheken

| # | Bibliothek | Quelle |
|:---:|---|---|
| [14] | Adafruit SH110X | Adafruit Industries: *Adafruit_SH110x*. https://github.com/adafruit/Adafruit_SH110x |
| [15] | Adafruit GFX | Adafruit Industries: *Adafruit-GFX-Library*. https://github.com/adafruit/Adafruit-GFX-Library |
| [16] | Adafruit BusIO | Adafruit Industries: *Adafruit_BusIO*. https://github.com/adafruit/Adafruit_BusIO |
| [17] | MFRC522 | Miguel Balboa u. a.: *rfid – Arduino RFID Library for MFRC522*. https://github.com/miguelbalboa/rfid |
| [18] | Keypad (nur `hardware_test`) | Mark Stanley, Alexander Brevig: *Keypad*. https://github.com/Chris--A/Keypad |
| [19] | `Wire`, `SPI`, `EEPROM` | Bestandteil der Arduino IDE ([20]) |

✏️ TODO (Team): Versionsnummern der installierten Bibliotheken eintragen
(Arduino IDE → Library Manager → Filter „Installiert“).

## Werkzeuge

| # | Werkzeug | Wofür | Quelle |
|:---:|---|---|---|
| [20] | Arduino IDE | Programmieren, Hochladen, serieller Monitor | https://www.arduino.cc/en/software |
| [21] | Cirkit Designer | Schaltplan | https://www.cirkitdesigner.com |
| [22] | OpenSCAD | 3D-Modell des Gehäuses | https://openscad.org |
| [23] | three.js | Interaktives 3D-Modell im Browser | https://threejs.org |
| [24] | Git und GitHub | Versionsverwaltung, Wiki, Veröffentlichung des 3D-Modells | https://github.com/BBZ-AIFS51/LF7-Projekt_GAS |
| [25] | Claude Code (Anthropic) | KI-Assistent als Hilfsmittel beim Programmieren und bei der Fehlersuche, siehe [KI-Einsatz](KI-Einsatz) | https://claude.com/claude-code |
| [26] | ✏️ TODO (Team) | Slicer für den 3D-Druck (z. B. PrusaSlicer, Cura) | ✏️ TODO |

---

<sub>← [9 Fazit und Ausblick](Fazit-und-Ausblick) · [Anhang: Team und Rollen](Team-und-Rollen) →</sub>

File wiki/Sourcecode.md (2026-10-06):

<!-- Diese Seite wird automatisch aus dem Ordner wiki/ im Repository erzeugt. Änderungen im Wiki-Editor werden beim nächsten Abgleich überschrieben. Bearbeiten: https://github.com/BBZ-AIFS51/LF7-Projekt_GAS/tree/main/wiki -->
# 6 · 📄 Sourcecode

Der vollständige Sourcecode liegt als eigene Dateien bei und ist hier nicht
abgedruckt. Die wichtigsten Stellen sind in [Kapitel 7](Wichtige-Codeabschnitte)
erklärt.

## Dateien

| Datei | Zweck | Umfang |
|---|---|---:|
| **[`Code/alarm_system/alarm_system.ino`](https://github.com/BBZ-AIFS51/LF7-Projekt_GAS/blob/main/Code/alarm_system/alarm_system.ino)** | **Hauptfirmware:** Zustandsautomat, PIN, RFID, Admin-Menü, Töne, Display | ca. 1050 Zeilen |
| [`Code/hardware_test/hardware_test.ino`](https://github.com/BBZ-AIFS51/LF7-Projekt_GAS/blob/main/Code/hardware_test/hardware_test.ino) | Inbetriebnahme: prüft Display, Keypad, Buzzer und Bewegungsmelder einzeln | ca. 210 Zeilen |
| [`Code/display_test/display_test.ino`](https://github.com/BBZ-AIFS51/LF7-Projekt_GAS/blob/main/Code/display_test/display_test.ino) | nur das Display: Symbole im Wechsel, gibt den freien Arbeitsspeicher aus | ca. 130 Zeilen |
| [`Code/rfid_test/rfid_test.ino`](https://github.com/BBZ-AIFS51/LF7-Projekt_GAS/blob/main/Code/rfid_test/rfid_test.ino) | nur der RFID-Leser: prüft das Modul und zeigt die Kennung jeder Karte | ca. 90 Zeilen |

Die Arduino IDE verlangt, dass jeder Sketch in einem eigenen Ordner mit
gleichem Namen liegt, daher die Unterordner.

> [!NOTE]
> ✏️ **TODO (Team):** Abgabeform eintragen, z. B. „Die Dateien liegen der
> Abgabe als `Sourcecode.zip` bei“ oder „Stand: Tag `v1.0` im Repository“.

## Kompilieren und hochladen

1. Arduino IDE installieren und über den Library Manager installieren:
   **Adafruit SH110X** (mit Abhängigkeiten *Adafruit GFX* und *Adafruit
   BusIO*) und **MFRC522**.
2. Oben in `alarm_system.ino` PIN und Admin-PIN festlegen (`PIN_CODE`,
   `ADMIN_PIN`).
3. Board **Arduino Uno** und den richtigen Port wählen, hochladen.
4. Seriellen Monitor auf **9600 Baud** stellen. Beim Start erscheinen die
   Version des RFID-Lesers, die Zahl der gespeicherten Karten und der freie
   Arbeitsspeicher.

## Einstellungen im Code

Alle Zeiten und Grenzwerte stehen als Konstanten am Anfang der Hauptfirmware und
lassen sich dort ändern, ohne den restlichen Code anzufassen:

| Konstante | Wert | Bedeutung |
|---|---:|---|
| `EXIT_DELAY_MS` | 10 000 ms | Ausgangsverzögerung nach dem Scharfschalten |
| `ALARM_MS` | 30 000 ms | Dauer der Sirene |
| `ERROR_TONE_MS` | 2 000 ms | Dauer des Fehlertons |
| `MAX_WRONG_TRIES` | 3 | Fehlversuche bis zum Alarm |
| `ENTRY_TIMEOUT_MS` | 10 000 ms | halb getippte PIN wird gelöscht |
| `ADMIN_IDLE_TIMEOUT_MS` | 20 000 ms | Admin-Menü schließt bei Inaktivität |
| `MAX_STORED_UIDS` | 8 | maximale Zahl gespeicherter Karten |
| `RFID_POLL_MS` | 200 ms | Abstand zwischen zwei Abfragen des RFID-Lesers |

> [!NOTE]
> ✏️ **TODO (Team):** Gefordert war ein Fehlerton von 3 s, im Code stehen 2 s
> (`ERROR_TONE_MS`). Entweder auf `3000UL` ändern oder hier begründen, warum
> 2 s besser passen.

---

<sub>← [5 Aufbau und Schaltplan](Aufbau-und-Schaltplan) · [7 Wichtige Codeabschnitte](Wichtige-Codeabschnitte) →</sub>

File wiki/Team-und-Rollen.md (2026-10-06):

<!-- Diese Seite wird automatisch aus dem Ordner wiki/ im Repository erzeugt. Änderungen im Wiki-Editor werden beim nächsten Abgleich überschrieben. Bearbeiten: https://github.com/BBZ-AIFS51/LF7-Projekt_GAS/tree/main/wiki -->
# 👥 Team und Rollen

<sub>Anhang</sub>

Wer am Projekt beteiligt war, wer welche Aufgaben übernommen hat und mit
welchen Werkzeugen wir gearbeitet haben.

## Team

> [!NOTE]
> ✏️ **TODO (Team):** Tabelle ausfüllen, eine Zeile pro Person. Auch Arbeit,
> die nicht im Repository sichtbar ist (Recherche, Aufbau, Löten, Testen,
> 3D-Druck, Präsentation), gehört hierher.

| Name | Rolle | Hauptaufgaben |
|---|---|---|
| ✏️ TODO | z. B. Projektleitung, Firmware | ✏️ TODO |
| ✏️ TODO | z. B. Hardware-Aufbau, Tests | ✏️ TODO |
| ✏️ TODO | z. B. Gehäuse, Dokumentation | ✏️ TODO |

## Aufgabenverteilung

> [!NOTE]
> ✏️ **TODO (Team):** In der Tabelle eintragen, wer was gemacht hat:
> **V** = verantwortlich, **M** = mitgearbeitet.

| Aufgabe | ✏️ Person 1 | ✏️ Person 2 | ✏️ Person 3 |
|---|:---:|:---:|:---:|
| Projektidee und Anforderungen | | | |
| Bauteile besorgen | | | |
| Hardware-Aufbau und Verdrahtung | | | |
| Bring-up-Tests der Bauteile | | | |
| Firmware (mit Claude Code) | | | |
| Testen am echten Aufbau | | | |
| RFID-Erweiterung und Admin-Menü | | | |
| Gehäuse: Planung und Druck | | | |
| README, 3D-Modell, Grafiken | | | |
| Wiki und Projektdokumentation | | | |
| Präsentation | | | |

## Werkzeuge

| Werkzeug | Wofür |
|---|---|
| **Arduino IDE** | Sketches kompilieren und auf den Uno hochladen, serieller Monitor |
| **Git und GitHub** | Versionsverwaltung, Wiki, GitHub Pages für das 3D-Modell |
| **Cirkit Designer** | [Schaltplan](https://github.com/BBZ-AIFS51/LF7-Projekt_GAS/blob/main/Schaltplan/SCHALTPLAN.png) |
| **Claude Code** | KI-Assistent für Firmware, Doku und Gehäuse, siehe [KI-Einsatz](KI-Einsatz) |
| **OpenSCAD** | Parametrisches 3D-Modell des [Gehäuses](https://github.com/BBZ-AIFS51/LF7-Projekt_GAS/blob/main/MDs/gehaeuse.md) |
| **three.js** | [3D-Modell im Browser](https://bbz-aifs51.github.io/LF7-Projekt_GAS/) |
| ✏️ TODO | Slicer und 3D-Drucker, mit dem gedruckt wird |

## Zusammenarbeit

> [!NOTE]
> ✏️ **TODO (Team):** Kurz beschreiben, wie ihr euch abgestimmt habt.
> Zum Beispiel: Wo habt ihr gearbeitet (Unterricht, zu Hause)? Wie habt ihr
> kommuniziert? Wer hat in das Repository gepusht?

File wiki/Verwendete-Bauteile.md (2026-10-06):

<!-- Diese Seite wird automatisch aus dem Ordner wiki/ im Repository erzeugt. Änderungen im Wiki-Editor werden beim nächsten Abgleich überschrieben. Bearbeiten: https://github.com/BBZ-AIFS51/LF7-Projekt_GAS/tree/main/wiki -->
# 4 · 🧩 Verwendete Bauteile

Alle Bauteile des Projekts und wofür sie eingesetzt werden. Preise und
Bezugsquellen stehen im Anhang unter [Kosten](Kosten), die Verdrahtung in
[Kapitel 5](Aufbau-und-Schaltplan).

## Elektronik

| Bauteil | Typ / Kenndaten | Aufgabe im Projekt |
|---|---|---|
| 🧠 **Mikrocontroller** | Arduino Uno R3 (ATmega328P, 16 MHz, 32 KB Flash, **2 KB SRAM**, 1 KB EEPROM) | Das „Gehirn“: fragt alle Eingaben ab, führt den Zustandsautomaten aus und steuert Display und Buzzer. Im internen EEPROM liegen die erlaubten RFID-Karten. |
| ⌨️ **Tastenfeld** | 4x4-Folien-Keypad, 16 Tasten, 8 Anschlüsse (4 Reihen, 4 Spalten) | PIN-Eingabe, Bestätigen (<kbd>#</kbd>), Löschen (<kbd>*</kbd>), Admin-Menü (<kbd>A</kbd>) und RFID-Reset (<kbd>B</kbd>) |
| 🖥️ **Display** | OLED 1,3 Zoll, 128 × 64 Pixel, monochrom, Controller **SH1106**, I²C, Adresse `0x3C` | Zeigt den Zustand als Symbol (Herz, Totenkopf, ✖), die PIN als `*`, Countdowns und das Admin-Menü |
| 📶 **RFID-Leser** | RC522-Modul (NXP MFRC522), 13,56 MHz, SPI, **Versorgung 3,3 V** | Liest die Kennung (UID) von Karten und Schlüsselanhängern, zweiter Weg zum Scharf- und Unscharfschalten |
| 💳 **RFID-Karte und -Anhänger** | MIFARE Classic, 4-Byte-UID | „Schlüssel“ für berechtigte Personen. Welche Karten gelten, wird im Admin-Menü festgelegt. |
| 👁️ **Bewegungsmelder** | PIR-Sensor HC-SR501 (Joy-IT SEN-HC-SR501), Erfassungswinkel ca. 120°, Reichweite bis ca. 7 m, Ausgang HIGH bei Bewegung | Erkennt, wenn jemand den Raum betritt, und löst im scharfen Zustand den Alarm aus |
| 🔊 **Buzzer** | Passiver Piezo-Summer | Alle Töne: Tastenklick, Bestätigung, Fehlerton, Piepen der Ausgangsverzögerung, Sirene |
| 🔋 **Stromversorgung** | 9-V-Batterie mit Hohlstecker (alternativ USB) | Versorgt den Arduino. Alle Module hängen an dessen 5-V- bzw. 3,3-V-Pin. |
| 🔗 **Breadboard und Jumper-Kabel** | Steckbrett, Steckbrücken | Gemeinsame 5-V- und GND-Schiene, Verbindungen ohne Löten |

> [!NOTE]
> **Warum ein passiver Buzzer?** Ein aktiver Buzzer piept mit einer festen
> Tonhöhe, sobald Spannung anliegt. Ein passiver Buzzer braucht ein
> Rechtecksignal vom Arduino (`tone()`), kann dafür aber jede Tonhöhe spielen.
> Nur so sind heller Bestätigungston, tiefer Fehlerton und eine auf- und
> abschwellende Sirene möglich.

> [!NOTE]
> **Warum SH1106 und nicht SSD1306?** Die meisten Anleitungen für 128x64-OLEDs
> nutzen den Controller SSD1306. Unser 1,3-Zoll-Display hat aber einen SH1106.
> Mit der falschen Library bleibt es leer oder zeigt Streifen, siehe
> [Herausforderungen](Herausforderungen#oled-display-bleibt-leer).

## Software und Bibliotheken

| Bibliothek | Wofür |
|---|---|
| Adafruit SH110X | Ansteuerung des OLED-Displays (Klasse `Adafruit_SH1106G`) |
| Adafruit GFX | Zeichnen von Formen und Text (Herz, Totenkopf, Countdown) |
| Adafruit BusIO | Hilfsschicht für I²C, wird von SH110X benötigt |
| MFRC522 | Ansteuerung des RFID-Lesers |
| `Wire`, `SPI`, `EEPROM` | I²C-Bus, SPI-Bus und Kartenspeicher, in der Arduino IDE enthalten |
| Keypad | nur im Test-Sketch `hardware_test`. Die Hauptfirmware scannt das Tastenfeld selbst, siehe [Kapitel 7](Wichtige-Codeabschnitte#75-tastenfeld-selbst-abfragen). |

Quellen zu allen Bauteilen und Bibliotheken: [Quellenverzeichnis](Quellenverzeichnis).

## Gehäuse

Für das 3D-gedruckte Gehäuse kommen fünf Druckteile aus PLA, Schrauben und ein
3-adriges Kabel zum Sensorteil dazu. Die vollständige Liste steht unter
[Kosten](Kosten#gehäuse), Planung und Bauanleitung in der
[Gehäuse-Anleitung](https://github.com/BBZ-AIFS51/LF7-Projekt_GAS/blob/main/MDs/gehaeuse.md).

---

<sub>← [3 Funktionsbeschreibung](Funktionsbeschreibung) · [5 Aufbau und Schaltplan](Aufbau-und-Schaltplan) →</sub>

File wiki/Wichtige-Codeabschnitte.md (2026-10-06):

<!-- Diese Seite wird automatisch aus dem Ordner wiki/ im Repository erzeugt. Änderungen im Wiki-Editor werden beim nächsten Abgleich überschrieben. Bearbeiten: https://github.com/BBZ-AIFS51/LF7-Projekt_GAS/tree/main/wiki -->
# 7 · 🧠 Wichtige Codeabschnitte

Die zentralen Stellen der Hauptfirmware
[`alarm_system.ino`](https://github.com/BBZ-AIFS51/LF7-Projekt_GAS/blob/main/Code/alarm_system/alarm_system.ino),
erklärt. Das übliche Grundgerüst (Variablen, `setup()`, Zeichenfunktionen für
die Symbole) ist nicht aufgeführt. Die Ausschnitte sind gekürzt: Testausgaben
über den seriellen Monitor sind weggelassen, `// …` markiert größere Lücken.
Die Kommentare im Code sind auf Englisch.

| Abschnitt | Funktionen im Code |
|---|---|
| [7.1 Programmablauf: nichts darf blockieren](#71-programmablauf-nichts-darf-blockieren) | `loop()` |
| [7.2 Zustandsautomat](#72-zustandsautomat) | `setState()`, `updateState()` |
| [7.3 Zugriff erlaubt oder verweigert](#73-zugriff-erlaubt-oder-verweigert) | `accessGranted()`, `accessDenied()` |
| [7.4 Bewegung erkennen](#74-bewegung-erkennen) | `handleMotion()` |
| [7.5 Tastenfeld selbst abfragen](#75-tastenfeld-selbst-abfragen) | `scanKeypad()`, `getKeyPress()` |
| [7.6 RFID-Karten lesen und speichern](#76-rfid-karten-lesen-und-speichern) | `readNewCardUid()`, `loadUidsFromEeprom()` |
| [7.7 Töne ohne Warten](#77-töne-ohne-warten) | `updateSound()` |
| [7.8 Arbeitsspeicher sparen](#78-arbeitsspeicher-sparen) | `F()`, `PROGMEM` |

## 7.1 Programmablauf: nichts darf blockieren

```cpp
void loop() {
  if (state == STATE_ADMIN) {
    handleAdminKeypad();
    handleAdminRfid();
  } else {
    handleKeypad();
    handleRfid();
  }
  handleMotion();
  updateState();
  updateSound();
  updateDisplay();
}
```

`loop()` ruft nur kurze Funktionen nacheinander auf und läuft so viele tausend
Mal pro Sekunde. Jede Funktion schaut nach, ob es für sie etwas zu tun gibt, und
kehrt sofort zurück.

**Wichtigste Entscheidung im ganzen Programm:** Es gibt kein `delay()`. Würde der
Code zum Beispiel für die 30 Sekunden Sirene `delay(30000)` aufrufen, könnte in
dieser Zeit niemand die PIN eingeben, um den Alarm zu beenden. Stattdessen merkt
sich das Programm, **wann** etwas angefangen hat (`millis()`), und prüft bei
jedem Durchlauf, ob die Zeit schon um ist. So reagiert die Anlage immer sofort
auf Tasten, Karten und Bewegung, auch während Töne laufen.

## 7.2 Zustandsautomat

```cpp
enum SystemState { STATE_DISARMED, STATE_EXIT_DELAY, STATE_ARMED, STATE_ALARM, STATE_ADMIN };
SystemState state = STATE_DISARMED;

void setState(SystemState next) {
  state = next;
  stateStart = millis();          // remember when this state began
  // …
}

void updateState() {
  unsigned long now = millis();

  if (state == STATE_EXIT_DELAY) {
    // … one short beep per second …
    if (now - stateStart >= EXIT_DELAY_MS) {
      setState(STATE_ARMED);
    }
  } else if (state == STATE_ALARM) {
    if (now - stateStart >= ALARM_MS) {
      stopSound();
      setState(STATE_ARMED);      // siren over, stay armed
    }
  }
}
```

- Die Variable `state` hält fest, in welchem der fünf Zustände die Anlage gerade
  ist (Diagramm in [Kapitel 3](Funktionsbeschreibung#zustände-der-anlage)). Ein
  `enum` macht den Code lesbar: `STATE_ARMED` statt einer Zahl wie `2`.
- Jeder Zustandswechsel läuft über `setState()`. Dort wird die Startzeit
  gespeichert. Damit kann `updateState()` mit einer einfachen Subtraktion
  prüfen, ob die Ausgangsverzögerung (10 s) oder die Sirene (30 s) abgelaufen
  ist.
- **Nach dem Alarm geht die Anlage zurück auf SCHARF, nicht auf UNSCHARF.**
  Sonst könnte ein Einbrecher einfach 30 Sekunden warten und wäre danach
  unbemerkt im Raum.

> [!NOTE]
> `now - stateStart >= …` funktioniert auch dann, wenn `millis()` nach etwa
> 49 Tagen überläuft und wieder bei 0 anfängt. Ein Vergleich wie
> `now >= stateStart + ALARM_MS` würde in diesem Moment falsch rechnen.

## 7.3 Zugriff erlaubt oder verweigert

PIN und RFID-Karte landen am Ende in denselben zwei Funktionen. Dadurch verhalten
sich beide Wege garantiert gleich.

```cpp
void accessGranted() {
  wrongTries = 0;
  switch (state) {
    case STATE_ALARM:
    case STATE_ARMED:
    case STATE_EXIT_DELAY:
      setState(STATE_DISARMED);   // anything active -> disarm
      break;
    case STATE_DISARMED:
      setState(STATE_EXIT_DELAY); // disarmed -> start arming
      break;
  }
  startSound(SOUND_OK);
}

void accessDenied(const __FlashStringHelper *reason) {
  if (state == STATE_ALARM) {
    return;                       // wrong entry must not stop the siren
  }
  wrongTries++;
  if (wrongTries >= MAX_WRONG_TRIES) {
    wrongTries = 0;
    triggerAlarm(reason);
  } else {
    startSound(SOUND_ERROR);
  }
}
```

- **Richtige Eingabe** schaltet um: Ist die Anlage aktiv (Ausgangsverzögerung,
  scharf oder Alarm), wird sie unscharf. Ist sie unscharf, startet die
  Ausgangsverzögerung. Der Zähler für Fehlversuche wird zurückgesetzt.
- **Falsche Eingabe** erhöht den Zähler. Beim dritten Mal (`MAX_WRONG_TRIES`)
  gibt es Alarm, sonst nur den Fehlerton. Das verhindert, dass jemand die PIN
  einfach durchprobiert.
- **Während des Alarms** wird eine falsche Eingabe ignoriert. Vorher hat der
  Fehlerton die Sirene ersetzt, und nach dem Fehlerton war Ruhe (siehe
  [Herausforderungen](Herausforderungen#falsche-eingabe-beendet-den-alarm)).

Die PIN selbst wird in `submitEntry()` mit `strcmp(entry, PIN_CODE)` verglichen,
also Zeichen für Zeichen mit der gespeicherten PIN.

## 7.4 Bewegung erkennen

```cpp
void handleMotion() {
  bool motion = (digitalRead(MOTION_PIN) == HIGH);

  // rising edge only, so one long detection does not retrigger endlessly
  if (motion && !lastMotion && state == STATE_ARMED) {
    triggerAlarm(F("motion detected"));
  }
  lastMotion = motion;
}
```

- Der Bewegungsmelder liefert HIGH, solange er Bewegung sieht. Ausgewertet wird
  nur der **Wechsel von LOW auf HIGH** (steigende Flanke): `motion` ist jetzt
  wahr, `lastMotion` vom letzten Durchlauf war falsch. So löst eine einzige,
  längere Bewegung den Alarm nur einmal aus.
- Die Bedingung `state == STATE_ARMED` sorgt dafür, dass Bewegung im unscharfen
  Zustand und während der Ausgangsverzögerung keine Rolle spielt.
- Beim Scharfschalten setzt `setState()` den Wert `lastMotion` auf den
  aktuellen Sensorwert. Sieht der Sensor in diesem Moment noch die Person, die
  gerade gegangen ist, zählt das nicht als neue Bewegung.

## 7.5 Tastenfeld selbst abfragen

Die übliche Keypad-Library brauchte rund 120 Byte Arbeitsspeicher, die der Uno
nicht übrig hatte (siehe [7.8](#78-arbeitsspeicher-sparen)). Deshalb fragt die
Firmware die Tastenmatrix selbst ab.

```cpp
char scanKeypad() {
  char found = 0;
  for (byte c = 0; c < 4 && found == 0; c++) {
    pinMode(COL_PINS[c], OUTPUT);     // pull this column low
    delayMicroseconds(5);             // let the line settle
    for (byte r = 0; r < 4; r++) {
      if (digitalRead(ROW_PINS[r]) == LOW) {
        found = pgm_read_byte(&KEYS[r][c]);
        break;
      }
    }
    pinMode(COL_PINS[c], INPUT);      // back to high-Z
  }
  return found;
}
```

- Die 16 Tasten sitzen an den Kreuzungen von 4 Reihen und 4 Spalten. Eine
  gedrückte Taste verbindet ihre Reihe mit ihrer Spalte.
- Die Reihen-Pins haben einen internen **Pull-up-Widerstand** und lesen
  normalerweise HIGH. Die Schleife zieht nacheinander je eine Spalte auf LOW.
  Liest dabei eine Reihe LOW, ist genau die Taste an dieser Kreuzung gedrückt.
- Welches Zeichen zu Reihe und Spalte gehört, steht in der Tabelle `KEYS`.

`getKeyPress()` **entprellt** das Ergebnis: Ein mechanischer Kontakt flattert
beim Drücken ein paar Millisekunden zwischen offen und geschlossen. Eine Taste
zählt erst, wenn sie 20 ms (`DEBOUNCE_MS`) stabil gedrückt ist, und wird nur
einmal pro Druck gemeldet.

## 7.6 RFID-Karten lesen und speichern

```cpp
bool readNewCardUid() {
  if (!rfidOk || millis() - lastRfidPoll < RFID_POLL_MS) {
    return false;                     // ask the reader only every 200 ms
  }
  lastRfidPoll = millis();

  if (!mfrc522.PICC_IsNewCardPresent() || !mfrc522.PICC_ReadCardSerial()) {
    return false;
  }
  // …
  mfrc522.PICC_HaltA();               // send the card to sleep
  return true;
}
```

- Jede Karte hat eine feste Kennung, die **UID** (bei unseren Karten 4 Byte).
  Die Firmware vergleicht sie Byte für Byte mit der Liste der erlaubten Karten
  (`findStoredUid()`).
- Der Leser wird **nur alle 200 ms** gefragt. Liegt keine Karte auf, wartet
  eine Abfrage etwa 25 ms auf eine Antwort. Bei jedem Durchlauf von `loop()`
  würde das Tastenfeld träge und die Sirene stockend.
- `PICC_HaltA()` schickt die Karte schlafen. Eine liegengelassene Karte schaltet
  die Anlage dadurch nicht ständig hin und her.

**Speicherung im EEPROM:** Die erlaubten Karten stehen nicht im Code, sondern im
EEPROM des Uno. Dieser Speicher behält seinen Inhalt ohne Strom und auch beim
erneuten Hochladen des Sketches.

| Adresse | Inhalt |
|---|---|
| 0 | Kennbyte `0xA5`: „hier wurde schon einmal gespeichert“ |
| 1 | Anzahl gespeicherter Karten |
| ab 2 | je 4 Byte pro Karte |

Fehlt das Kennbyte, ist der Chip neu. Dann schreibt `loadUidsFromEeprom()` eine
Startliste hinein. Gespeichert wird mit `EEPROM.update()`, das eine Zelle nur
beschreibt, wenn sich ihr Wert ändert. Das schont den Speicher, der nur etwa
100 000 Schreibvorgänge pro Zelle verträgt.

## 7.7 Töne ohne Warten

```cpp
case SOUND_ALARM: {
  unsigned long phase = t % 500UL;               // 500 ms up/down cycle
  unsigned long step  = (phase % 250UL) / 10UL;  // 0..24
  int freq = (phase < 250UL) ? (2500 + (int)step * 50)
                             : (3700 - (int)step * 50);
  setFreq(freq);
  break;
}
```

- Alle Töne funktionieren nach demselben Prinzip wie der Zustandsautomat:
  `t` ist die Zeit seit Beginn des Tons. Daraus wird bei jedem Durchlauf die
  passende Frequenz berechnet.
- **Sirene:** In jeder halben Sekunde steigt die Frequenz in 25 Stufen von
  2500 Hz auf 3700 Hz und fällt wieder ab. In diesem Bereich ist der Buzzer am
  lautesten, das Auf und Ab macht den Ton schrill und auffällig.
- **Fehlerton:** wechselt alle 35 ms zwischen 95 Hz und 135 Hz. Dadurch klingt
  er rau und brummend.
- **Bestätigung:** zwei kurze, helle Töne (1568 Hz, dann 2093 Hz).
- `setFreq()` ruft `tone()` nur auf, wenn sich die Frequenz wirklich ändert.
  Sonst würde der Ton bei jedem Durchlauf neu gestartet und knacken.

## 7.8 Arbeitsspeicher sparen

Der Uno hat nur **2048 Byte** Arbeitsspeicher (SRAM). Das Display braucht davon
allein 1024 Byte als Bildpuffer. Wird der Rest knapp, überschreibt das Programm
seine eigenen Daten: Das Display zeigt Pixelmüll, der Arduino startet neu oder
erkennt Tasten falsch (siehe [Herausforderungen](Herausforderungen#arbeitsspeicher-zu-knapp)).

```cpp
Serial.println(F("=== Alarm system ready (disarmed) ==="));

const char KEYS[4][4] PROGMEM = {
  {'1', '2', '3', 'A'},
  // …
};
```

- `F("…")` lässt einen Text im Flash-Speicher (32 KB) und kopiert ihn nicht in
  den Arbeitsspeicher. Das gilt für alle Texte der Firmware.
- `PROGMEM` macht dasselbe für feste Tabellen wie die Tastenbelegung. Gelesen
  wird dann mit `pgm_read_byte()`.
- Keine Keypad-Library, kein `snprintf`, keine Textpuffer. Beim Start gibt die
  Firmware den freien Speicher über den seriellen Monitor aus (`freeRam()`).

> [!NOTE]
> ✏️ **TODO (Team):** Gemessenen Wert eintragen: Beim Start meldet die Firmware
> `free SRAM: ___` Byte. (Vorher, mit Keypad-Library: 205 Byte.)

---

<sub>← [6 Sourcecode](Sourcecode) · [8 Herausforderungen](Herausforderungen) →</sub>

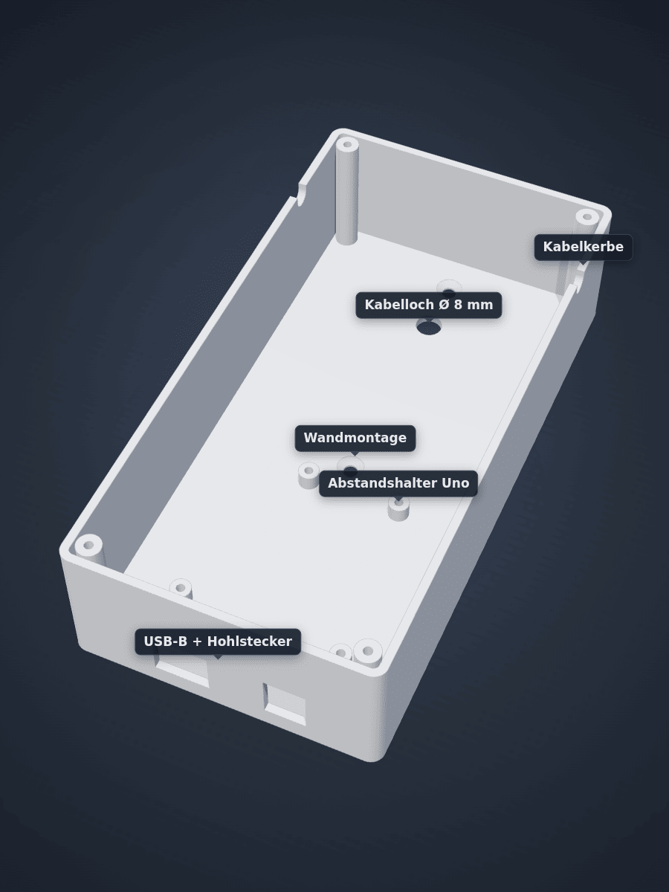
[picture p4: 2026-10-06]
Gehaeuse/bilder/rueckteil.png

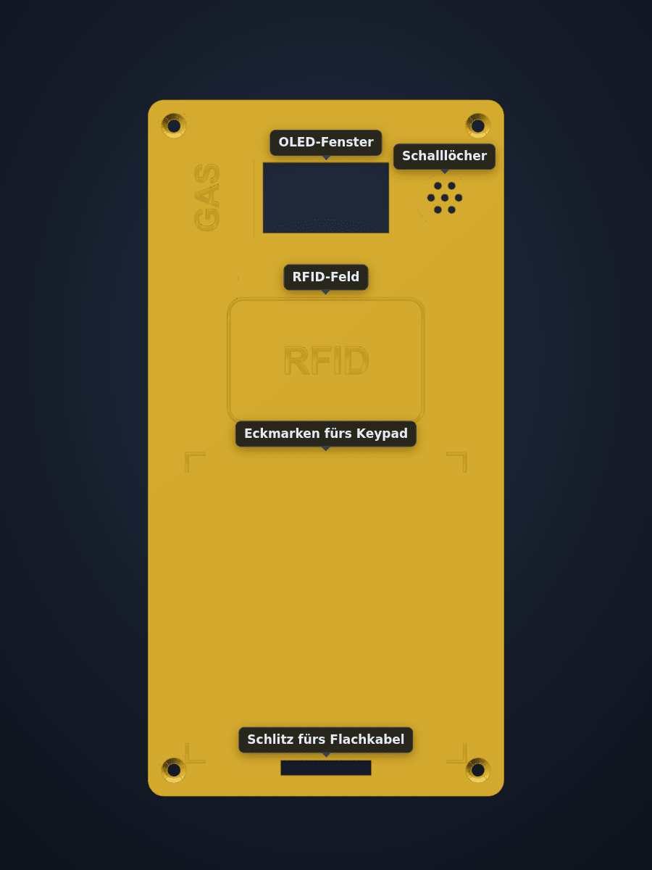
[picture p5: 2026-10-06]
Gehaeuse/bilder/frontansicht.png

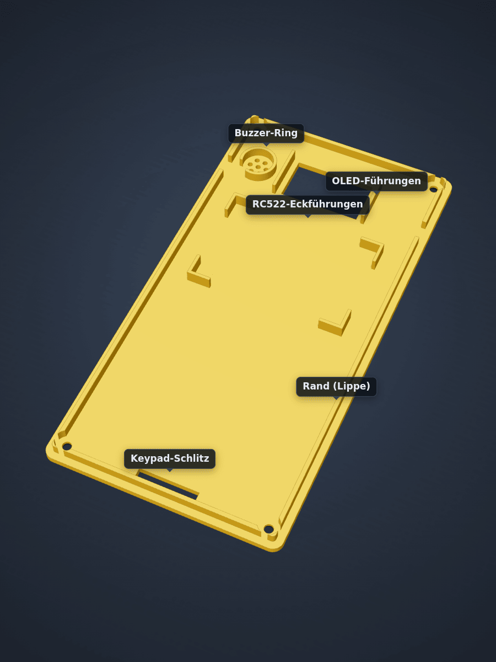
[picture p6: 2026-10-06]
Gehaeuse/bilder/front_innen.png

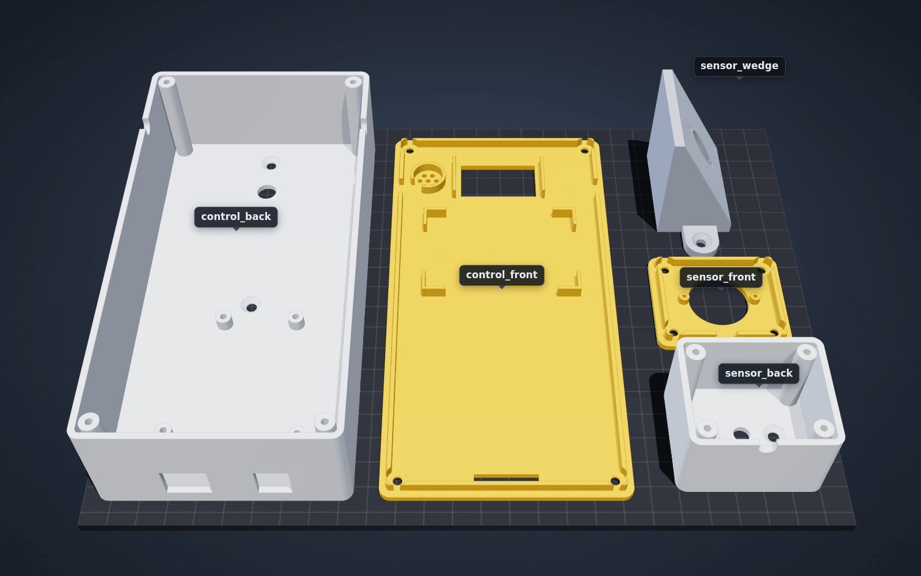
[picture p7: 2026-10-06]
Gehaeuse/bilder/druckplatte.png

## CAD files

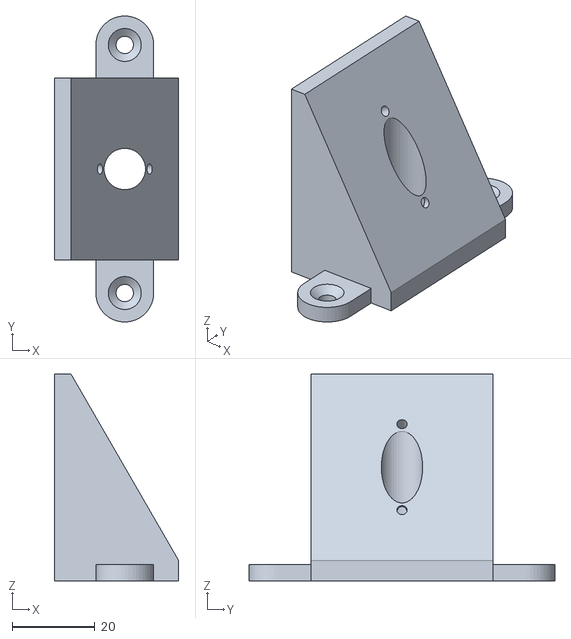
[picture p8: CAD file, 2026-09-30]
Gehaeuse/stl/sensor_wedge.stl
30.0 x 74.0 x 50.0

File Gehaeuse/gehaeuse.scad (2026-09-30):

// Enclosure for Projekt GAS (LF07)
//
// Two separate enclosures:
//   1. Control unit (outside, next to the door frame):
//      membrane keypad, OLED, RFID-RC522, passive buzzer, Arduino Uno
//   2. Sensor unit (inside the room): HC-SR501 motion sensor
//
// Usage (OpenSCAD, free: https://openscad.org):
//   - choose a value for "part" below (or in the Customizer panel)
//   - F6 = render, then File > Export > Export as STL
//   - all *_back / *_front parts are already in print orientation
//
// All sizes in mm. Values in the section "Measured parts" come from
// data sheets - check them with a ruler before printing.

/* [Part selection] */
part = "assembly"; // [assembly, exploded, sensor_assembly, control_back, control_front, sensor_back, sensor_front, sensor_wedge]

/* [General] */
wall = 2.4;           // side wall thickness (6 lines with a 0.4 nozzle)
floor_t = 2.4;        // back plate thickness
lid_t = 2.4;          // front plate thickness
corner_r = 4;         // outer corner radius
clr = 0.3;            // gap between lid lip and walls
lip_t = 1.6;          // thickness of the lid lip
lip_h = 4;            // height of the lid lip
boss_d = 7;           // screw boss diameter
boss_inset = 6.5;     // screw boss centre, measured from the outer edge
pilot_d = 2.5;        // pilot hole for 3 mm screws
screw_d = 3.4;        // clearance hole for 3 mm screws
csk_d = 6.4;          // countersink diameter for the lid screws
wall_screw_d = 4.2;   // wall mounting screws (up to 4 mm)
wall_csk_d = 8;
guide_t = 1.2;        // thickness of the positioning guides
guide_h = 5;          // height of the positioning guides
fit = 0.25;           // play per side around modules
engrave = 0.6;        // depth of the engravings on the front

/* [Control unit] */
cu_w = 90;            // outer width
cu_depth = 40;        // inner depth (back plate to lid)

/* [Measured parts - check with a ruler!] */
keypad_w = 69.5;      // membrane keypad without ribbon
keypad_h = 77;
ribbon_slot_w = 23;   // must let the 8-pin plug through
ribbon_slot_h = 4;
rfid_w = 60;          // RC522 board
rfid_h = 40;
oled_w = 36;          // 1.3" SH1106 board
oled_h = 34;
oled_win_w = 32;      // window, active area is about 29.4 x 14.7
oled_win_h = 18;
buzzer_d = 12;        // buzzer body on the KY-006 style module
uno_standoff_h = 5;

/* [Sensor unit] */
su_w = 52;
su_h = 44;
su_depth = 30;        // inner depth, room for the plugs under the sensor
pir_w = 32.3;         // HC-SR501 board
pir_h = 24.3;
pir_hole_dist = 28;   // distance of the two mounting holes
pir_dome_d = 23;      // Fresnel lens diameter
pir_post_h = 3;       // gap between lid and sensor board
su_angle = 60;        // wedge angle: sensor turned towards the door
wedge_min = 5;        // wedge thickness at its thin end (door side)
wedge_back = 4;       // extra material behind the thick end (screw holes)
tab_t = 4;            // thickness of the wall mounting tabs on the wedge

$fn = 48;

// ---------------------------------------------------------------------------
// Derived layout of the control unit
// Front view, origin = bottom-left outer corner, x right, y up, z to the front
// ---------------------------------------------------------------------------

UNO_W = 53.34;
UNO_L = 68.58;
// Uno mounting holes, board upright with the USB/power jacks at the bottom
UNO_HOLES = [[2.54, 15.24], [17.78, 66.04], [45.72, 66.04], [50.8, 13.97]];

lip_in = wall + clr + lip_t;          // outer edge -> inner side of the lip
cu_cx = cu_w / 2;
slot_y = lip_in + 0.8;                // ribbon slot directly below the keypad
kp_x = cu_cx - keypad_w / 2;
kp_y = slot_y + ribbon_slot_h;
rfid_cy = kp_y + keypad_h + 4 + rfid_h / 2;
oled_cy = rfid_cy + rfid_h / 2 + 3 + guide_t + oled_h / 2;
cu_h = ceil(oled_cy + oled_h / 2 + 3 + lip_in);
cu_th = floor_t + cu_depth;           // height of the back part
buzzer_x = (cu_cx + oled_w / 2 + fit + guide_t + cu_w - lip_in) / 2;

uno_x = cu_cx - UNO_W / 2;
uno_y = wall + 6.2 + 0.4;             // USB jack sticks out 6.2 mm
uno_z = floor_t + uno_standoff_h;

mount_y = [uno_y + UNO_L + 7, cu_h - 14];
cable_y = 145;
notch_w = 6;
notch_d = 5;

su_th = floor_t + su_depth;
wedge_l = su_w * cos(su_angle);       // wedge length along the wall
wedge_max = wedge_min + su_w * sin(su_angle);

// ---------------------------------------------------------------------------
// Helpers
// ---------------------------------------------------------------------------

module rrect(w, h, r) {
    translate([r, r]) offset(r = r) square([w - 2 * r, h - 2 * r]);
}

// rounded rectangle shrunk by d on every side
module rrect_inset(w, h, r, d) {
    translate([d, d]) rrect(w - 2 * d, h - 2 * d, max(r - d, 0.5));
}

function boss_pos(w, h) = [
    [boss_inset, boss_inset], [w - boss_inset, boss_inset],
    [boss_inset, h - boss_inset], [w - boss_inset, h - boss_inset]
];

// countersunk hole, head at z = top
module csk_hole(d, dk, top) {
    cone_h = (dk - d) / 2;
    translate([0, 0, -1]) cylinder(d = d, h = top + 2);
    translate([0, 0, top - cone_h]) cylinder(d1 = d, d2 = dk, h = cone_h + 0.01);
    translate([0, 0, top]) cylinder(d = dk, h = 50);
}

// open box: back plate, walls and four screw bosses
module shell_back(w, h, th) {
    difference() {
        union() {
            difference() {
                linear_extrude(th) rrect(w, h, corner_r);
                translate([0, 0, floor_t])
                    linear_extrude(th) rrect_inset(w, h, corner_r, wall);
            }
            intersection() {
                linear_extrude(th) rrect(w, h, corner_r);
                for (p = boss_pos(w, h))
                    translate(p) cylinder(d = boss_d, h = th);
            }
        }
        for (p = boss_pos(w, h))
            translate([p[0], p[1], th - 12]) cylinder(d = pilot_d, h = 13);
    }
}

// lid: plate (z = 0 .. lid_t, front face on top) and lip hanging down
module shell_front(w, h) {
    difference() {
        union() {
            linear_extrude(lid_t) rrect(w, h, corner_r);
            translate([0, 0, -lip_h]) linear_extrude(lip_h) difference() {
                rrect_inset(w, h, corner_r, wall + clr);
                rrect_inset(w, h, corner_r, wall + clr + lip_t);
                for (p = boss_pos(w, h)) translate(p) circle(d = boss_d + 1);
            }
        }
        for (p = boss_pos(w, h))
            translate([p[0], p[1], -lip_h]) csk_hole(screw_d, csk_d, lip_h + lid_t);
    }
}

// cut a cable notch into the rim of a wall (x/y = centre of the notch)
module rim_notch(x, y, horizontal, th) {
    translate([x, y, th - notch_d + notch_w / 2]) {
        rotate(horizontal ? [90, 0, 0] : [0, 90, 0])
            cylinder(d = notch_w, h = 20, center = true);
        translate([0, 0, 25]) cube([horizontal ? notch_w : 20, horizontal ? 20 : notch_w, 50], center = true);
    }
}

// remove the lid lip where a rim notch is (x/y = centre of the notch)
module lip_cut(x, y, horizontal) {
    translate([x, y, -lip_h / 2 - 0.5])
        cube([horizontal ? notch_w + 2 : 20, horizontal ? 20 : notch_w + 2, lip_h + 1], center = true);
}

// four L-shaped corner guides around a w x h pocket, hanging below z = 0
module corner_guides(w, h, leg = 8) {
    pw = w + 2 * fit;
    ph = h + 2 * fit;
    translate([0, 0, -guide_h]) linear_extrude(guide_h) difference() {
        square([pw + 2 * guide_t, ph + 2 * guide_t], center = true);
        square([pw, ph], center = true);
        square([pw - 2 * leg, ph + 10], center = true);
        square([pw + 10, ph - 2 * leg], center = true);
    }
}

// line drawing of a rounded rectangle (for engravings)
module rrect_line(w, h, r, lw) {
    difference() {
        translate([-w / 2, -h / 2]) rrect(w, h, r);
        translate([-w / 2, -h / 2]) rrect_inset(w, h, r, lw);
    }
}

// L-shaped corner mark, legs pointing along +x and +y
module corner_mark(leg = 5, lw = 0.8) {
    square([leg, lw]);
    square([lw, leg]);
}

// ---------------------------------------------------------------------------
// Control unit
// ---------------------------------------------------------------------------
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

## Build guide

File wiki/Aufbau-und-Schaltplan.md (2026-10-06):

<!-- Diese Seite wird automatisch aus dem Ordner wiki/ im Repository erzeugt. Änderungen im Wiki-Editor werden beim nächsten Abgleich überschrieben. Bearbeiten: https://github.com/BBZ-AIFS51/LF7-Projekt_GAS/tree/main/wiki -->
# 5 · 🔌 Aufbau und Schaltplan

Wie die Bauteile verdrahtet sind: Schaltplan, Pin-Zuordnung und ein Foto vom
echten Aufbau zum Vergleich.

## Schaltplan

<p align="center">
  <a href="https://github.com/BBZ-AIFS51/LF7-Projekt_GAS/blob/main/Schaltplan/SCHALTPLAN.png">Schaltplan: Arduino Uno mit Keypad, OLED, RFID-RC522, Buzzer, Bewegungsmelder und 9-V-Batterie</a><br>
  <sub>Erstellt mit Cirkit Designer · Bild anklicken für volle Größe · auch als <a href="https://github.com/BBZ-AIFS51/LF7-Projekt_GAS/blob/main/Schaltplan/SCHALTPLAN.svg">SVG</a></sub>
</p>

## Pin-Zuordnung

| Bauteil | Anschluss am Bauteil | Pin am Uno | Bus / Signal |
|---|---|---|---|
| ⌨️ Keypad | Reihen R1, R2, R3, R4 | D9, D8, D7, D6 | digital, Matrix |
| ⌨️ Keypad | Spalten C1, C2, C3, C4 | D5, D4, D3, D2 | digital, Matrix |
| 🖥️ OLED | SDA · SCL | **A4 · A5** | I²C (fest vorgegeben) |
| 📶 RFID-RC522 | SDA/SS · RST | A0 · A1 | SPI-Auswahl, Reset |
| 📶 RFID-RC522 | MOSI · MISO · SCK | **D11 · D12 · D13** | SPI (fest vorgegeben) |
| 📶 RFID-RC522 | VCC | **3,3 V** | ⚠️ nicht 5 V |
| 👁️ Bewegungsmelder | OUT | A2 | digital, HIGH = Bewegung |
| 🔊 Buzzer | Signal (S) | D10 | `tone()` |
| alle anderen Module | VCC · GND | 5 V · GND | gemeinsame Schienen auf dem Breadboard |

Damit ist der Uno fast voll: Frei sind nur noch A3 und D0/D1. D0/D1 sind die
serielle Schnittstelle zum PC und werden für Upload und Testausgaben gebraucht.

> [!WARNING]
> **Der RFID-Leser läuft mit 3,3 V.** An 5 V wird das Modul zerstört. Alle
> anderen Module bekommen 5 V.

### Warum diese Pins?

- **I²C und SPI liegen beim Uno auf festen Pins.** Das Display muss an A4/A5,
  die Datenleitungen des RFID-Lesers an D11–D13. Nur die Auswahl- und
  Reset-Leitung des Lesers (A0, A1) ist frei wählbar.
- **Der Bewegungsmelder ist umgezogen.** Er saß zuerst auf D11. Als der
  RFID-Leser dazukam, wurde D11 als SPI-Leitung gebraucht, deshalb hängt der
  Sensor jetzt an A2. Die analogen Pins funktionieren auch als normale
  Digitalpins.
- **Das Keypad braucht 8 Pins** (D2–D9), weil jede Reihe und jede Spalte eine
  eigene Leitung hat.

## Verdrahtung als Übersicht

<p align="center">
  Animierte Übersicht: Verdrahtung aller Bauteile mit dem Arduino Uno
</p>

## Foto vom Versuchsaufbau

<table>
  <tr>
    <td align="center" width="50%">Schaltplan<br><sub>Schaltplan</sub></td>
    <td align="center" width="50%">✏️ <b>TODO (Team):</b> Foto<br><sub>Echter Aufbau auf dem Breadboard</sub></td>
  </tr>
</table>

> [!IMPORTANT]
> ✏️ **TODO (Team):** Foto vom echten Aufbau machen (von oben, alle Kabel gut
> zu sehen) und im Repository unter `wiki/images/aufbau.jpg` ablegen. Dann in der
> Tabelle oben die rechte Zelle ersetzen durch:
> `<img src="https://raw.githubusercontent.com/BBZ-AIFS51/LF7-Projekt_GAS/main/wiki/images/aufbau.jpg" alt="Versuchsaufbau">`
>
> Am besten gleich prüfen, ob Schaltplan und Foto übereinstimmen, vor allem
> die 3,3 V am RFID-Leser und der Bewegungsmelder an A2.

## Gehäuse

Für den Einsatz an der Tür gibt es zwei 3D-gedruckte Gehäuse, verbunden über
ein 3-adriges Kabel (5 V, GND, Signal des Bewegungsmelders): das **Bedienteil**
außen mit Uno, Keypad, Display, RFID-Leser und Buzzer und das **Sensorteil**
innen. Ein 60°-Keil dreht den Bewegungsmelder zur Tür.

<table>
  <tr>
    <td align="center" width="50%">Bedienteil und Sensorteil zusammengebaut<br><sub>Bedienteil und Sensorteil auf dem Keil</sub></td>
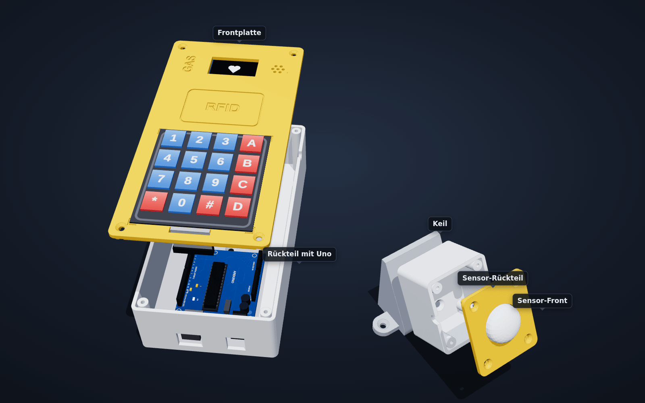
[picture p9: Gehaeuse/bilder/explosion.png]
Explosionszeichnung des Bedienteils
    <td align="center" width="50%"><br><sub>Explosionszeichnung des Bedienteils</sub></td>
  </tr>
</table>

Planung, Druckeinstellungen und Zusammenbau:
[Gehäuse-Anleitung](https://github.com/BBZ-AIFS51/LF7-Projekt_GAS/blob/main/MDs/gehaeuse.md) ·
im [3D-Modell](https://bbz-aifs51.github.io/LF7-Projekt_GAS/#enclosure) lässt
sich das Gehäuse aufklappen.

> [!NOTE]
> ✏️ **TODO (Team):** Sobald gedruckt, ein Foto vom echten Gehäuse ergänzen.

---

<sub>← [4 Verwendete Bauteile](Verwendete-Bauteile) · [6 Sourcecode](Sourcecode) →</sub>

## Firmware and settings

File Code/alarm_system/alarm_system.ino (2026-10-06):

/*
 * alarm_system.ino
 * Mini access / alarm system for the LF07 project (see MDs/aufbau.md).
 *
 * Behaviour
 *   - DISARMED  : heart icon on the OLED, motion sensor is ignored.
 *   - EXIT DELAY: skull + countdown, time to leave the room after arming.
 *   - ARMED     : skull icon, motion on the sensor triggers the alarm.
 *   - ALARM     : flashing skull + countdown, loud siren for 30 s
 *                 (or until the PIN is entered / a known card is presented).
 *
 * Two ways to arm and disarm
 *   Keypad : PIN + '#'
 *   RFID   : hold a known card (see "RFID admin menu" below) to the reader
 *   Both toggle the same way: disarmed -> exit delay -> armed, and armed or
 *   alarm -> disarmed. Three wrong PINs or unknown cards raise the alarm.
 *
 * Keypad
 *   0-9  enter PIN digits (shown as '*' only)
 *   #    confirm
 *   *    clear the current entry
 *   A    while disarmed and idle: enter the admin PIN to open the admin menu
 *   B    while disarmed: soft-reset the RFID reader (see resetRfid() below -
 *        the RC522 clones can occasionally stop answering over SPI)
 *   C-D  unused
 *
 * RFID admin menu (Keypad 'A' + ADMIN_PIN + '#', only while disarmed)
 *   Cards are no longer hard-coded: they live in the Uno's internal EEPROM,
 *   so they survive re-uploading the sketch and can be managed without a PC.
 *     1  add a card   - hold the new card to the reader
 *     2  list / delete cards - '#' next, 'D' delete shown card, '*' back
 *     *  leave the admin menu
 *   A wrong admin PIN counts as a wrong try, same as a wrong PIN_CODE.
 *   The menu times out back to normal operation after ADMIN_IDLE_TIMEOUT_MS.
 *
 * Feedback tones (passive buzzer on D10)
 *   accepted    : two short bright notes
 *   rejected    : rough low buzz, 3 s
 *   3x rejected : full alarm
 *
 * A wrong PIN or unknown card also shows a brief X icon on the OLED for the
 * length of the rejected-buzz, on top of whatever else is on screen.
 *
 * Wiring (see CLAUDE.md - changed when the RFID reader was added)
 *   Keypad rows R1..R4 -> D9, D8, D7, D6
 *   Keypad cols C1..C4 -> D5, D4, D3, D2
 *   Passive buzzer     -> D10
 *   Motion sensor OUT  -> A2  (active HIGH; moved off D11, that is SPI MOSI)
 *   OLED SH1106 128x64 -> SDA = A4, SCL = A5, I2C address 0x3C
 *   RC522 SS -> A0, RST -> A1, MOSI -> D11, MISO -> D12, SCK -> D13
 *   RC522 VCC -> 3.3V, NOT 5V
 *
 * MEMORY NOTE
 *   The Uno has 2048 bytes of SRAM and the OLED frame buffer alone takes 1024.
 *   With the Keypad library on top only ~205 bytes were left, which is not
 *   enough once tone() interrupts hit while the display code is deep in the
 *   stack - the result were random resets and corrupted key input. This sketch
 *   therefore scans the keypad itself (see scanKeypad()) and keeps every string
 *   in flash. The MFRC522 library costs about 15 bytes of static SRAM (mostly
 *   the Uid struct), so there is still room; setup() prints the free SRAM and
 *   it should stay well above 250.
 *
 * Libraries: Adafruit SH110X, Adafruit GFX, MFRC522, SPI, EEPROM
 *            (Keypad library NOT needed)
 * Serial Monitor: 9600 baud
 */

#include <Wire.h>
#include <SPI.h>
#include <EEPROM.h>
#include <Adafruit_GFX.h>
#include <Adafruit_SH110X.h>
#include <MFRC522.h>

// ---------------------------------------------------------------------------
// Settings - change these if needed
// ---------------------------------------------------------------------------
const char PIN_CODE[]  = "55559";                 // access code
const char ADMIN_PIN[] = "19283";                 // opens the RFID admin menu

const unsigned long ALARM_MS         = 30000UL;  // siren length
const unsigned long ERROR_TONE_MS    = 2000UL;   // wrong-PIN buzz length
const unsigned long EXIT_DELAY_MS    = 10000UL;  // time to leave after arming
const unsigned long ENTRY_TIMEOUT_MS = 10000UL;  // clear a half-typed PIN
const unsigned long ADMIN_IDLE_TIMEOUT_MS = 20000UL; // leave admin menu if idle
const unsigned long ADMIN_MSG_MS     = 1500UL;   // "Saved" / "Full" ... display time
const byte MAX_WRONG_TRIES = 3;                  // wrong tries before alarm
const byte MAX_ENTRY_LEN   = 8;                  // keypad input buffer
const byte DEBOUNCE_MS     = 20;                 // keypad debounce

// RFID cards that may arm / disarm the system are no longer hard-coded here:
// they are stored in the Uno's internal EEPROM and managed from the admin
// menu (keypad 'A' + ADMIN_PIN + '#'), see the UID storage section further
// down. DEFAULT_UIDS is only the factory list written to EEPROM the very
// first time the sketch runs on a blank chip - after that, edit cards from
// the menu, not here.
// These are 4-byte UIDs (MIFARE Classic cards and key fobs). If rfid_test
// reports 7 bytes instead, set UID_LEN to 7 and use 7 bytes per row.
const byte UID_LEN = 4;
const byte DEFAULT_UIDS[][UID_LEN] PROGMEM = {
  {0x9C, 0xEB, 0x1F, 0x49},   // key fob <-- REPLACE with your own UID
};
const byte DEFAULT_UID_COUNT = sizeof(DEFAULT_UIDS) / UID_LEN;

// EEPROM-backed UID storage. Deliberately small: the OLED frame buffer
// already eats most of the Uno's 2048 byte SRAM (see MEMORY NOTE above), and
// the school setup never needs more than a handful of cards.
const byte MAX_STORED_UIDS = 8;
const int  EEPROM_MAGIC_ADDR = 0;
const int  EEPROM_COUNT_ADDR = 1;
const int  EEPROM_DATA_ADDR  = 2;
const byte EEPROM_MAGIC = 0xA5;

byte storedUids[MAX_STORED_UIDS][UID_LEN];
byte storedUidCount = 0;

// How often the reader is polled. A poll with no card in front of it blocks
// for ~25 ms (the RC522 answer timeout), so polling on every loop pass would
// slow down the keypad and make the siren sweep choppy.
const unsigned long RFID_POLL_MS = 200UL;

// ---------------------------------------------------------------------------
// Pins
// ---------------------------------------------------------------------------
const byte ROW_PINS[4] = {9, 8, 7, 6};   // R1, R2, R3, R4
const byte COL_PINS[4] = {5, 4, 3, 2};   // C1, C2, C3, C4
const byte BUZZER_PIN = 10;
const byte MOTION_PIN = A2;              // moved: D11 is now SPI MOSI
const byte RFID_SS_PIN  = A0;            // RC522 SDA / SS
const byte RFID_RST_PIN = A1;            // RC522 RST
// SPI itself is fixed on the Uno: MOSI = D11, MISO = D12, SCK = D13

// keymap lives in flash - the Keypad library needed it in RAM
const char KEYS[4][4] PROGMEM = {
  {'1', '2', '3', 'A'},
  {'4', '5', '6', 'B'},
  {'7', '8', '9', 'C'},
  {'*', '0', '#', 'D'}
};

// ---------------------------------------------------------------------------
// OLED
// ---------------------------------------------------------------------------
#define SCREEN_WIDTH  128
#define SCREEN_HEIGHT 64
#define OLED_RESET    -1
#define OLED_ADDRESS  0x3C
Adafruit_SH1106G display(SCREEN_WIDTH, SCREEN_HEIGHT, &Wire, OLED_RESET);
bool oledOk = false;

// ---------------------------------------------------------------------------
// RFID reader
// ---------------------------------------------------------------------------
MFRC522 mfrc522(RFID_SS_PIN, RFID_RST_PIN);
bool rfidOk = false;
unsigned long lastRfidPoll = 0;

// ---------------------------------------------------------------------------
// State
// ---------------------------------------------------------------------------
enum SystemState { STATE_DISARMED, STATE_EXIT_DELAY, STATE_ARMED, STATE_ALARM, STATE_ADMIN };
SystemState state = STATE_DISARMED;

char entry[MAX_ENTRY_LEN + 1];
byte entryLen = 0;
unsigned long lastKeyMs = 0;
bool enteringAdmin = false;     // current entry[] is an admin PIN, not PIN_CODE

byte wrongTries = 0;
unsigned long stateStart = 0;   // start of exit delay / alarm
bool lastMotion = false;        // for rising-edge detection
bool displayDirty = true;

// ---------------------------------------------------------------------------
// Admin menu state (RFID cards, see uidAllowed()/addUid()/deleteUidAt())
// ---------------------------------------------------------------------------
enum AdminScreen { ADMIN_MENU, ADMIN_ADD_WAIT, ADMIN_LIST };
AdminScreen adminScreen = ADMIN_MENU;
byte adminListIndex = 0;
unsigned long lastAdminKeyMs = 0;
const __FlashStringHelper *adminMsg = nullptr;
unsigned long adminMsgUntil = 0;
unsigned long lastDraw = 0;

// Sound engine (non-blocking, so the keypad keeps working during a tone)
enum SoundId { SOUND_NONE, SOUND_OK, SOUND_ERROR, SOUND_ALARM };
SoundId sound = SOUND_NONE;
unsigned long soundStart = 0;
int currentFreq = -1;

void setup() {
  Serial.begin(9600);

  // SPI has to come up before the buzzer pin is set: SPI.begin() forces D10
  // (the AVR hardware SS pin) to OUTPUT HIGH, and D10 is our buzzer. Setting
  // the buzzer low afterwards leaves it in a defined, silent state.
  SPI.begin();
  mfrc522.PCD_Init();

  setupKeypad();
  pinMode(MOTION_PIN, INPUT);
  pinMode(BUZZER_PIN, OUTPUT);
  digitalWrite(BUZZER_PIN, LOW);

  entry[0] = '\0';

  oledOk = display.begin(OLED_ADDRESS, true);
  if (oledOk) {
    display.clearDisplay();
    display.display();
  } else {
    Serial.println(F("[OLED] not found - check SDA=A4 / SCL=A5 and address 0x3C"));
  }

  // VersionReg answers 0x91 / 0x92 on a genuine RC522. 0x00 or 0xFF means the
  // reader is not answering - wiring, or 5 V instead of 3.3 V on VCC.
  byte ver = mfrc522.PCD_ReadRegister(MFRC522::VersionReg);
  rfidOk = (ver != 0x00 && ver != 0xFF);
  Serial.print(F("[RFID] version 0x"));
  Serial.println(ver, HEX);
  if (!rfidOk) {
    Serial.println(F("[RFID] reader not found - check SS=A0, RST=A1 and 3.3V"));
    Serial.println(F("[RFID] keypad still works"));
  }

  loadUidsFromEeprom();

  Serial.println(F("=== Alarm system ready (disarmed) ==="));
  Serial.println(F("PIN + '#' or a known RFID card arms / disarms."));
  Serial.print(F("stored RFID cards: "));
  Serial.println(storedUidCount);
  Serial.print(F("free SRAM: "));
  Serial.println(freeRam());

  lastMotion = (digitalRead(MOTION_PIN) == HIGH);
  displayDirty = true;
}

void loop() {
  if (state == STATE_ADMIN) {
    handleAdminKeypad();
    handleAdminRfid();
  } else {
    handleKeypad();
    handleRfid();
  }
  handleMotion();
  updateState();
  updateSound();
  updateDisplay();
}

// free SRAM in bytes - if this gets close to 0 the frame buffer gets corrupted
int freeRam() {
  extern int __heap_start, *__brkval;
  int v;
  return (int)&v - (__brkval == 0 ? (int)&__heap_start : (int)__brkval);
}

// ---------------------------------------------------------------------------
// Keypad - own matrix scan instead of the Keypad library (saves ~120 byte RAM)
// ---------------------------------------------------------------------------
void setupKeypad() {
  for (byte i = 0; i < 4; i++) {
    pinMode(ROW_PINS[i], INPUT_PULLUP);
    digitalWrite(COL_PINS[i], LOW);   // set the level first, then release the
    pinMode(COL_PINS[i], INPUT);      // pin - avoids switching a pull-up on
  }
}

// key that is held down right now, 0 if none
char scanKeypad() {
  char found = 0;

  for (byte c = 0; c < 4 && found == 0; c++) {
    pinMode(COL_PINS[c], OUTPUT);     // pull this column low
    delayMicroseconds(5);             // let the line settle
    for (byte r = 0; r < 4; r++) {
      if (digitalRead(ROW_PINS[r]) == LOW) {
        found = pgm_read_byte(&KEYS[r][c]);
        break;
      }
    }
    pinMode(COL_PINS[c], INPUT);      // back to high-Z
  }
  return found;
}

// debounced, reports a key once when it is pressed down
char getKeyPress() {
  static char stableKey = 0;
  static char lastRead  = 0;
  static unsigned long lastChange = 0;

  char k = scanKeypad();

  if (k != lastRead) {                // still bouncing
    lastRead = k;
    lastChange = millis();
    return 0;
  }
  if (millis() - lastChange < DEBOUNCE_MS) {
    return 0;
  }
  if (k == stableKey) {               // nothing new
    return 0;
  }
  stableKey = k;
  return k;                           // 0 here means "key released"
}

// ---------------------------------------------------------------------------
// Keypad input
// ---------------------------------------------------------------------------
void handleKeypad() {
  // drop a half-typed PIN (or a lone 'A' admin request) after a while so
  // nothing stays on the screen and a later PIN entry is not misread as an
  // admin PIN
  if ((entryLen > 0 || enteringAdmin) && millis() - lastKeyMs > ENTRY_TIMEOUT_MS) {
    clearEntry();
    enteringAdmin = false;
    displayDirty = true;
  }

  char key = getKeyPress();
  if (key == 0) {
    return;
  }
  lastKeyMs = millis();

  Serial.print(F("[KEY] "));
  Serial.println(key);

  if (key >= '0' && key <= '9') {
    if (entryLen < MAX_ENTRY_LEN) {
      entry[entryLen++] = key;
      entry[entryLen] = '\0';
      clickBeep();
    }
    displayDirty = true;
  } else if (key == '*') {
    clearEntry();
    enteringAdmin = false;
    clickBeep();
    displayDirty = true;
  } else if (key == '#') {
    submitEntry();
  } else if (key == 'A' && state == STATE_DISARMED && entryLen == 0) {
    enteringAdmin = true;
    clickBeep();
    displayDirty = true;
  } else if (key == 'B' && state == STATE_DISARMED && entryLen == 0) {
    resetRfid();
  }
  // C-D are not used
}

void clearEntry() {
  entryLen = 0;
  entry[0] = '\0';
}

// Check the typed PIN (or, while enteringAdmin, the admin PIN) and act on it
void submitEntry() {
  if (enteringAdmin) {
    bool adminOk = (entryLen > 0 && strcmp(entry, ADMIN_PIN) == 0);
    enteringAdmin = false;
    clearEntry();
    displayDirty = true;

    if (adminOk) {
      Serial.println(F("[ADMIN] PIN correct, opening menu"));
      openAdminMenu();
    } else {
      Serial.println(F("[ADMIN] wrong PIN"));
      accessDenied(F("too many wrong admin PIN entries"));
    }
    return;
  }

  bool ok = (entryLen > 0 && strcmp(entry, PIN_CODE) == 0);

  Serial.print(F("[PIN] entered: "));
  Serial.println(entry);
  clearEntry();
  displayDirty = true;

  if (ok) {
    Serial.println(F("[PIN] correct"));
    accessGranted();
  } else {
    Serial.print(F("[PIN] wrong, try "));
    Serial.println(wrongTries + 1);
    accessDenied(F("too many wrong PIN entries"));
  }
}

// ---------------------------------------------------------------------------
// RFID - a known card does exactly what the correct PIN does
// ---------------------------------------------------------------------------

// Polls the reader; on a new card, leaves its UID in mfrc522.uid and returns
// true. Shared by normal operation and the admin "add card" screen.
bool readNewCardUid() {
  if (!rfidOk || millis() - lastRfidPoll < RFID_POLL_MS) {
    return false;
  }
  lastRfidPoll = millis();

  if (!mfrc522.PICC_IsNewCardPresent() || !mfrc522.PICC_ReadCardSerial()) {
    return false;
  }

  Serial.print(F("[RFID] uid:"));
  for (byte i = 0; i < mfrc522.uid.size; i++) {
    Serial.print(' ');
    Serial.print(mfrc522.uid.uidByte[i], HEX);
  }
  Serial.println();

  // HaltA sends the card to sleep, so leaving it on the reader does not
  // retrigger - it answers again only after being taken away and back.
  mfrc522.PICC_HaltA();
  return true;
}

// RC522 clones occasionally stop answering over SPI (VersionReg then reads
// 0x00/0xFF again). Re-running the reset/init sequence brings them back
// without a full board reset. Triggered manually via keypad 'B'.
void resetRfid() {
  Serial.println(F("[RFID] manual reset"));
  mfrc522.PCD_Reset();
  mfrc522.PCD_Init();

  byte ver = mfrc522.PCD_ReadRegister(MFRC522::VersionReg);
  rfidOk = (ver != 0x00 && ver != 0xFF);
  Serial.print(F("[RFID] version 0x"));
  Serial.println(ver, HEX);

  if (rfidOk) {
    startSound(SOUND_OK);
  } else {
    Serial.println(F("[RFID] still not answering"));
    startSound(SOUND_ERROR);
  }
}

void handleRfid() {
  if (!readNewCardUid()) {
    return;
  }

  if (uidAllowed()) {
    Serial.println(F("[RFID] known card"));
    accessGranted();
  } else {
    Serial.println(F("[RFID] unknown card"));
    accessDenied(F("too many unknown cards"));
  }
}

// is the UID just read one of the cards stored in EEPROM?
bool uidAllowed() {
  if (mfrc522.uid.size != UID_LEN) {
    return false;                        // wrong card family, cannot match
  }
  return findStoredUid(mfrc522.uid.uidByte) != -1;
}

// index of the given UID in storedUids, or -1 if it is not stored
int findStoredUid(const byte *uid) {
  for (byte c = 0; c < storedUidCount; c++) {
    bool match = true;
    for (byte i = 0; i < UID_LEN; i++) {
      if (uid[i] != storedUids[c][i]) {
        match = false;
        break;
      }
    }
    if (match) {
      return c;
    }
  }
  return -1;
}

// ---------------------------------------------------------------------------
// UID storage (EEPROM) - see "Settings" section above for the layout
// ---------------------------------------------------------------------------
void loadUidsFromEeprom() {
  if (EEPROM.read(EEPROM_MAGIC_ADDR) != EEPROM_MAGIC) {
    // blank / fresh chip - seed EEPROM with the factory default list
    storedUidCount = min(DEFAULT_UID_COUNT, MAX_STORED_UIDS);
    for (byte c = 0; c < storedUidCount; c++) {
      for (byte i = 0; i < UID_LEN; i++) {
        storedUids[c][i] = pgm_read_byte(&DEFAULT_UIDS[c][i]);
      }
    }
    saveUidsToEeprom();
    Serial.println(F("[EEPROM] blank chip, wrote factory default UIDs"));
    return;
  }

  storedUidCount = EEPROM.read(EEPROM_COUNT_ADDR);
  if (storedUidCount > MAX_STORED_UIDS) {
    Serial.println(F("[EEPROM] bad stored count, resetting to 0"));
    storedUidCount = 0;
    saveUidsToEeprom();
    return;
  }

  for (byte c = 0; c < storedUidCount; c++) {
    for (byte i = 0; i < UID_LEN; i++) {
      storedUids[c][i] = EEPROM.read(EEPROM_DATA_ADDR + c * UID_LEN + i);
    }
  }
}

// writes the magic byte, the count and every stored UID back to EEPROM.
// EEPROM.update() only actually writes a byte when its value changed, so
// repeated calls do not wear the EEPROM out.
void saveUidsToEeprom() {
  EEPROM.update(EEPROM_MAGIC_ADDR, EEPROM_MAGIC);
  EEPROM.update(EEPROM_COUNT_ADDR, storedUidCount);
  for (byte c = 0; c < storedUidCount; c++) {
    for (byte i = 0; i < UID_LEN; i++) {
      EEPROM.update(EEPROM_DATA_ADDR + c * UID_LEN + i, storedUids[c][i]);
    }
  }
}

// adds a UID if there is room and it is not already stored
bool addUid(const byte *uid) {
  if (storedUidCount >= MAX_STORED_UIDS) {
    return false;
  }
  for (byte i = 0; i < UID_LEN; i++) {
    storedUids[storedUidCount][i] = uid[i];
  }
  storedUidCount++;
  saveUidsToEeprom();
  return true;
}

// removes the UID at the given index, shifting the rest down
void deleteUidAt(byte index) {
  if (index >= storedUidCount) {
    return;
  }
  for (byte c = index; c < storedUidCount - 1; c++) {
    for (byte i = 0; i < UID_LEN; i++) {
      storedUids[c][i] = storedUids[c + 1][i];
    }
  }
  storedUidCount--;
  saveUidsToEeprom();
}

// ---------------------------------------------------------------------------
// Access decision - shared by keypad and RFID
// ---------------------------------------------------------------------------
void accessGranted() {
  wrongTries = 0;
  displayDirty = true;

  switch (state) {
    case STATE_ALARM:
    case STATE_ARMED:
    case STATE_EXIT_DELAY:
      setState(STATE_DISARMED);
      Serial.println(F("[STATE] disarmed"));
      break;
    case STATE_DISARMED:
      setState(STATE_EXIT_DELAY);
      Serial.println(F("[STATE] arming - exit delay running"));
      break;
  }
  startSound(SOUND_OK);
}

void accessDenied(const __FlashStringHelper *reason) {
  // while the siren runs, a wrong PIN/card must not interrupt or restart it -
  // only the correct PIN or a known card ends the alarm
  if (state == STATE_ALARM) {
    Serial.println(F("[ALARM] wrong entry ignored, siren keeps running"));
    return;
  }

  wrongTries++;
  displayDirty = true;

  if (wrongTries >= MAX_WRONG_TRIES) {
    wrongTries = 0;
    triggerAlarm(reason);
  } else {
    startSound(SOUND_ERROR);
  }
}

// ---------------------------------------------------------------------------
// Admin menu - manage RFID cards from the keypad/OLED, see CLAUDE.md
// ---------------------------------------------------------------------------
void openAdminMenu() {
  adminScreen = ADMIN_MENU;
  adminListIndex = 0;
  adminMsg = nullptr;
  lastAdminKeyMs = millis();
  setState(STATE_ADMIN);
  startSound(SOUND_OK);
}

void showAdminMsg(const __FlashStringHelper *msg) {
  adminMsg = msg;
  adminMsgUntil = millis() + ADMIN_MSG_MS;
  displayDirty = true;
}
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

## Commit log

2026-09-30 Adjusted Sensor Position on 3D-Print-Model
    [gehaeuse.scad, sensor_wedge.stl]
2026-09-30 Add enclosure tab to 3D viewer, re-render case pictures, social preview
    - Viewer: new "Enclosure" tab (#enclosure) with the parts inside the
    3D-printed case, built from the real STL files. Case can be shown
    solid, as X-ray or hidden and opened; wiring, cable to the sensor unit,
    cards and motion sensor keep working with the simulated firmware.
    - tools/stl2viewer.mjs packs Gehaeuse/stl/*.stl into docs/viewer/enclosure.js.
    - tools/render.mjs renders Gehaeuse/bilder/*.png and docs/social-preview.png
    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
2026-09-30 Show the 3D-printed case in the banner and the social preview
    - docs/banner.svg: the flat board is replaced by the control unit in its
    case (isometric, layout from gehaeuse.scad) and the sensor unit on its
    60 deg wedge; the animated story (heart, PIN, skull, alarm) is unchanged.
    - docs/social-preview.png: case rendered solid instead of X-ray.
    - Development log and CLAUDE.md updated.
    Claude-Session: https://claude.ai/code/session_01QBAWs3Ct5qNp8qju4AXY1h
2026-09-30 Banner and social preview in X-ray (holo) look
    - docs/banner.svg is now generated by tools/render.mjs from the template
    tools/banner.svg: an X-ray render of the case from the 3D viewer, with
    the animated OLED, key presses, RFID/buzzer/PIR rings and the card as
    SVG layers placed via projected plate coordinates (window.gasProject).
    - docs/social-preview.png back to the X-ray case.
    - CLAUDE.md, gehaeuse.md and development log updated.
    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
2026-10-06 Fixed Bug that Alarm Turns off after inserting wrong PIN or Card
    [alarm_system.ino]
2026-10-06 Restructure wiki rules after the documentation guidelines, log prompt 18
    The teacher's guidelines require ten fixed chapters and forbid printing
    prompts in the documentation. CLAUDE.md now describes the new wiki layout.
    Also fix the free-pin note: A3 is unused, not only D0/D1.
    Claude-Session: https://claude.ai/code/session_01MLo7qk4GTkjc3R2XgxSZ4M
2026-10-06 Publish the wiki from wiki/ with a GitHub Actions workflow
    The cloud session cannot push to the .wiki.git repo, so the wiki pages now
    live in wiki/ and .github/workflows/wiki.yml mirrors that folder into the
    wiki on every push to main. Uses only github.token, no third-party action.
    Also logs prompt 19 and documents the new flow in CLAUDE.md and README.
    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
2026-10-27 Fix banner header regex for CRLF, share viewer wiring table, update docs
2026-10-29 Power the Uno from a 9 V battery on VIN, add the mini breadboard plan
    The case is printed. The battery now sits inside the control unit and feeds
    VIN instead of the barrel jack, power is shared out on a mini breadboard
    (SYB-170): column 13 = 5 V, column 15 = GND, column 17 (lower half) = 9 V.
    - new hand-drawn plan Schaltplan/steckplan_gehaeuse.svg
    - viewer: battery on VIN in both tabs, battery and new layout in the case
    - wiring.svg: battery on VIN, A3 listed as free
    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
2026-11-03 Stronger sensor screw posts, battery on VIN in the schematic
    sensor_front: the two posts for the HC-SR501 were free-standing 4 mm tubes
    with 1.2 mm walls and broke off. Each post is now a solid web running out
    into the lid lip (the lens frame leaves no room inwards), and the pilot
    holes are deep enough for M2 x 6. STL, viewer data and the print plate
    render regenerated.
    SCHALTPLAN.svg/.png: battery rewired from the barrel jack to VIN (red) and
    GND (black), edited in the export since the Cirkit project is not in the
    repo. Docs, log entries 21/22 and the wiki updated.
